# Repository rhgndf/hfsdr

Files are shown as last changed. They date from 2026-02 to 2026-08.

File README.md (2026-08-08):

# hfsdr

HFSDR: host software, firmware, and hardware design for the HFSDR USB device.




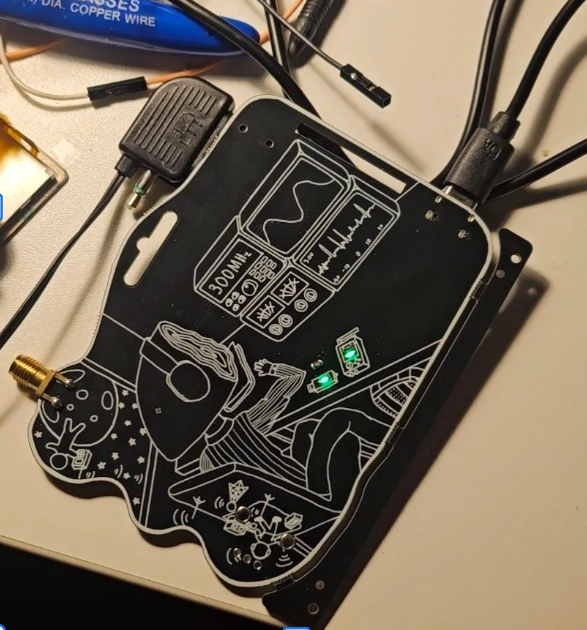
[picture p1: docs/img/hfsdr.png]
hfsdr


[Board PCB Files viewer](https://rhgndf.github.io/hfsdr/hardware)

## Getting started

Portable Mode (not connected to a PC)

1. Press the Rotary Encoder to 
    1. Enable/ Disable FM Audio Out mode (on disabled, it plays a constant tone)
    2. Cycle through different LED modes
<!--2. Turn the radio to change the FM Radio Frequency-->

Connected to a PC

1. Go to [the web ui](https://rhgndf.github.io/hfsdr/)
2. Connect & Pair a device
3. Set the frequency & gain
4. Pair the device again
5. Waterfall of the wireless world should start. If it doesn't look like [this](https://hackin7.github.io/lain-sdr-chall/assets/sample-C2LA0HHR.png), unplug the device and try again

- **User manual (slides):** [HFSDR User Manual](https://docs.google.com/presentation/d/1T5zb-2KSN37Saw5E9nwcajVOSR3CzVYfAOpIypQLBcQ/edit?usp=sharing)
- **Lain Themed Web UI** [lain-sdr-ui](https://hackin7.github.io/lain-sdr-chall)
- **Host testing (Python probe, GNU Radio `.grc` examples, drivers, protocol):** [docs/host-guide.md](docs/host-guide.md)

## Troubleshooting

- **No firmware:** Enter the bootloader by holding down BOOT and pressing the RST button. Use `wchisp` to flash the elf file in the releases
- **USB / stream flaky:** Unplug the board or reset it a few times. The host stack sometimes needs a power cycle before enumeration, WinUSB binding, or streaming stabilizes.
- **Using with GNURadio/ Python Scripting:** See the driver and probe sections in [docs/host-guide.md](docs/host-guide.md).
- **Reset:** Do not hold the reset button for too long 

## Repository layout

| Path | Contents |
|---|---|
| `ch32v305/` | Firmware (CH32V305). Build, flash, toolchain: [ch32v305/README.md](ch32v305/README.md). |
| `client-sw/` | Host Python (`hfsdr_probe`, PyUSB helpers), GNU Radio blocks and examples (`gr-hfsdr-lib`, `.grc`). |
| `docs/` | [host-guide.md](docs/host-guide.md) — primary host-side documentation. |
| `hardware/` | KiCad project and related hardware files. |
| `scripts/` | Helper scripts (e.g. udev `99-hfsdr.rules`, Windows USB checks). |
| `ui/` | WebUSB Web UI (Svelte/Vite). Deployed build: `homepage` in [ui/package.json](ui/package.json). |

## Credits

1. rhgndf - hard carry schematic & everything inside actually
2. Hackin7 - Art, PCB rough layout & routing & some embedded
3. Hack & Roll Cursor Credits + Codex - allow us to do this while being overseas/ having full time jobs
4. https://github.com/ttrftech/CentSDR - Useful reference

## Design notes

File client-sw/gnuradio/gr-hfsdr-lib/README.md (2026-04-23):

# gr-hfsdr-lib

Python-first GNU Radio source scaffold for HFSDR over the USB vendor endpoint.

Full host setup (drivers, probe, opening example `.grc` files, protocol): [docs/host-guide.md](../../../docs/host-guide.md).

## What this scaffold provides

- `python/hfsdr_source.py`: GNU Radio `sync_block` source outputting `gr_complex`.
- `python/hfsdr_usb.py`: PyUSB transport and vendor control requests.
- `grc/hfsdr_hfsdr_source.block.yml`: GRC block description for quick graph wiring.

## Dependencies

- GNU Radio 3.10+
- Python packages:
  - `numpy`
  - `pyusb`

Install:

```bash
py -3 -m pip install -r client-sw/host/python/requirements.txt
```

## Quick use from Python flowgraph

```python
import os
import sys
sys.path.insert(0, os.path.abspath("client-sw/gnuradio/gr-hfsdr-lib/python"))
from hfsdr_source import hfsdr_source

src = hfsdr_source(sample_rate=192000, vid=0xCAFE, pid=0x4031, interface=4, endpoint_in=0x85)
```

## Runtime controls

- `set_lo_hz(hz)`
- `get_lo_hz()`
- `set_gain_raw(gain_raw)`
- `get_pll_locked()`
- `get_stats()`

You can also set `gain_raw` in the GRC block parameters and enable
`apply_gain_on_start` to program TLV320 gain when the flowgraph starts.

## Notes

- The source claims only the vendor interface, so CDC and UAC interfaces remain available.
- This is an initial scaffold intended for rapid bring-up. If needed, migrate to a full compiled OOT layout later.

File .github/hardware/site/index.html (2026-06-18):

KiCad CI review

# __PROJECT_NAME__

Run GitHub Actions

Commit unknown

ERC / DRC unknown

Outputs unknown

3D unknown

## KiCanvas

Interactive schematic and PCB view from the source files in this run.

## Visual Diff

Schematic and PCB differences for this pull request.

### Visual diff

Open full SVG

## 3D Model

The browser VRML viewer is enabled automatically when a board model is available.

### No browser-viewable 3D model in this run

The 3D model job did not publish model/board.wrl for this project.

## ERC and DRC Reports

Generated by KiBot during the validation job.

### ERC

Open full report

### DRC

Open full report

## Downloads

Fabrication and assembly files from this run.

Generic BOM CSV Generic fabrication ZIP JLCPCB Gerbers ZIP JLCPCB BOM CSV JLCPCB CPL CSV Interactive BOM

## PDFs

Schematic and PCB layer plots from KiBot.

Schematic Front copper Back copper Front silkscreen Back silkscreen Front mask Back mask Front fab Back fab Edge cuts

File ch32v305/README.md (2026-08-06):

# ch32v305

Firmware build for the CH32V305 SDR target.

## Requirements

- `cmake` 3.20 or newer
- `ninja`
- RISC-V GCC bare-metal toolchain in `PATH`
  - expected tools: `riscv-none-elf-gcc`, `riscv-none-elf-g++`, `riscv-none-elf-ar`, `riscv-none-elf-size`

## Build With Ninja

Configure the project with the Ninja generator:

```bash
cmake -S . -B build -G Ninja
```

Build it:

```bash
cmake --build build
```

The main output is:

- `build/ch32v305_sdr.elf`

The linker also emits:

- `build/ch32v305_sdr.map`

## Flash

From the build directory:

```bash
cd build
wchisp flash ch32v305_sdr.elf
```

## Notes

- Link-time output includes `--print-memory-usage`.
- A post-build `riscv-none-elf-size` report is also printed.
- FreeRTOS Kernel is a submodule pinned to V11.3.0. Initialize submodules before
  building a fresh checkout:

  ```bash
  git submodule update --init --recursive
  ```
- All FreeRTOS objects and tasks use static allocation. The task layout is:

  | Task | Priority | Stack |
  | --- | ---: | ---: |
  | I2S processing | 3 | 192 words / 768 bytes |
  | TinyUSB device | 2 | 256 words / 1024 bytes |
  | Hardware state | 2 | 256 words / 1024 bytes |
  | Recording | 2 | 432 words / 1728 bytes |
  | Application/UI | 1 | 432 words / 1728 bytes |
  | FreeRTOS idle | 0 | 144 words / 576 bytes |

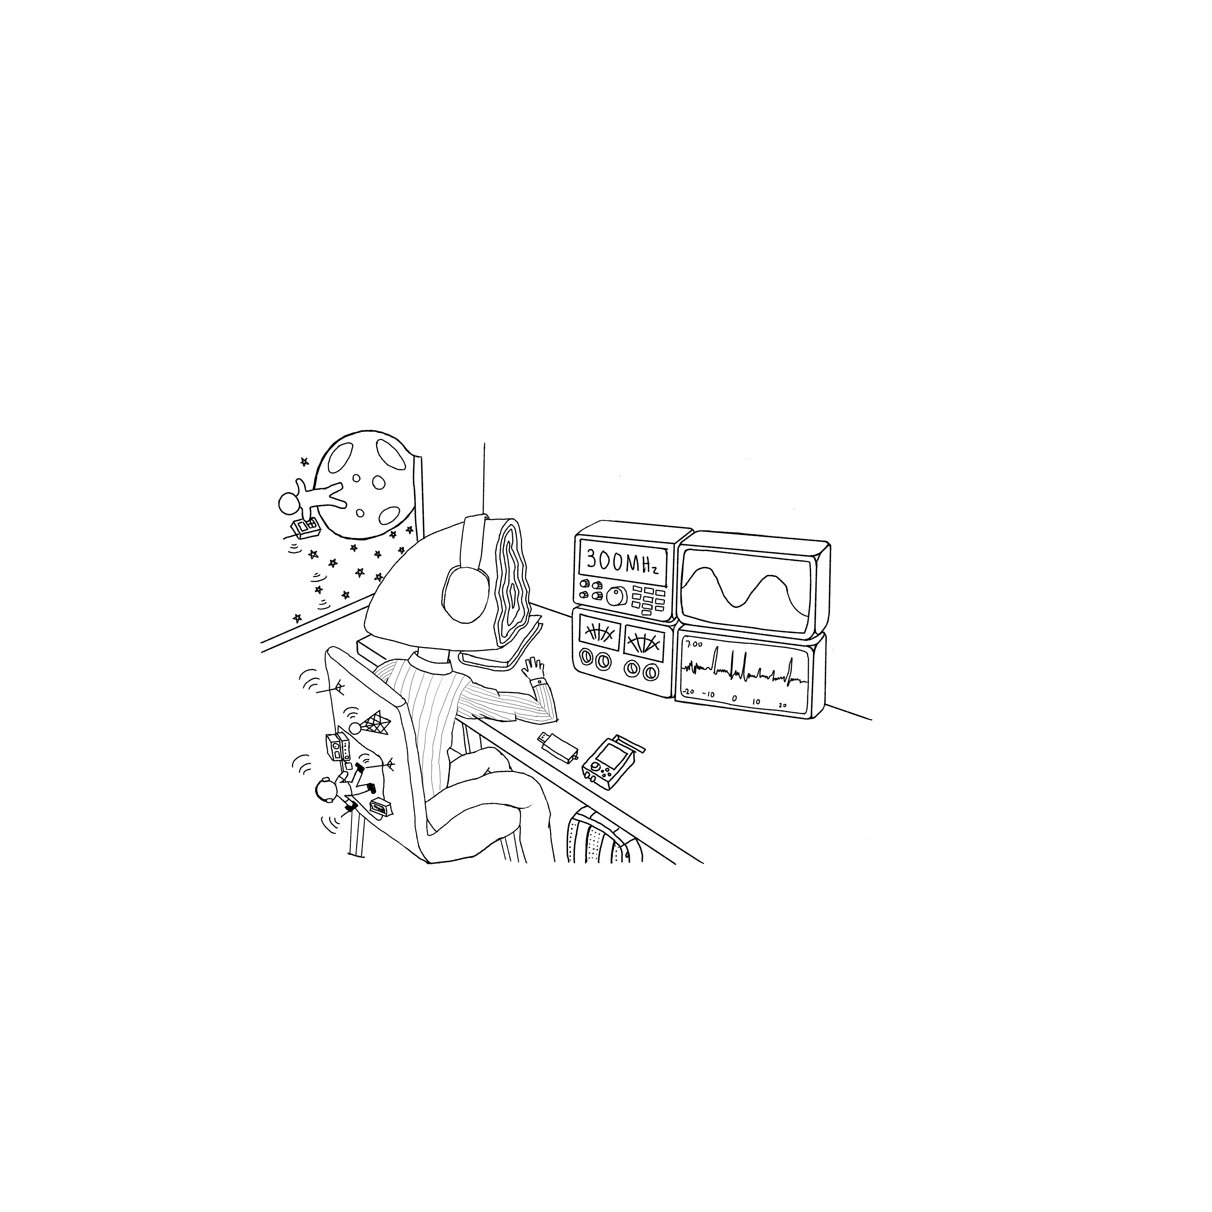
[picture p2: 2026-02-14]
art/art_export/design1- silkscreen.png

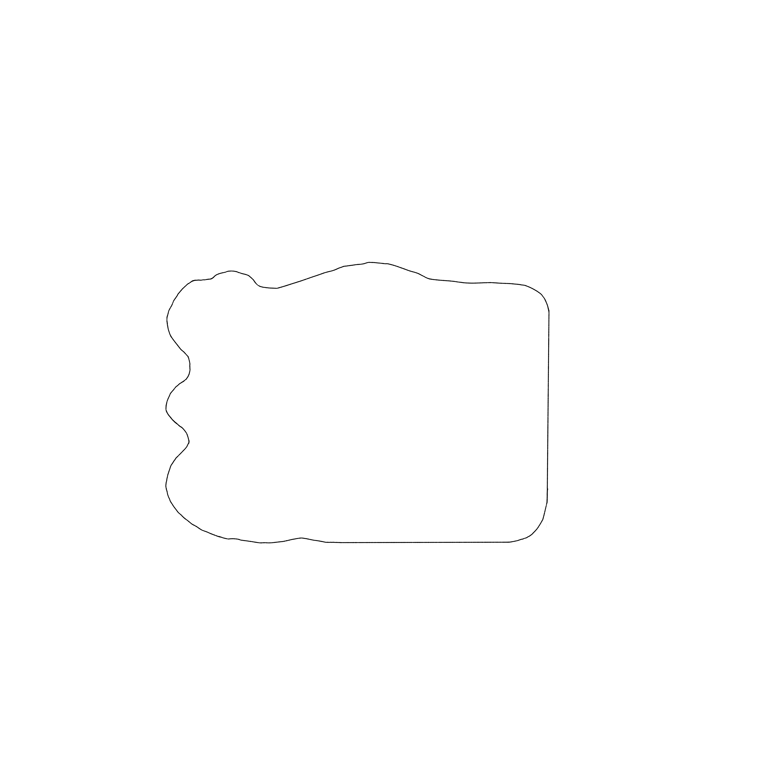
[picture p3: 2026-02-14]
art/art_export/design1-outline.png

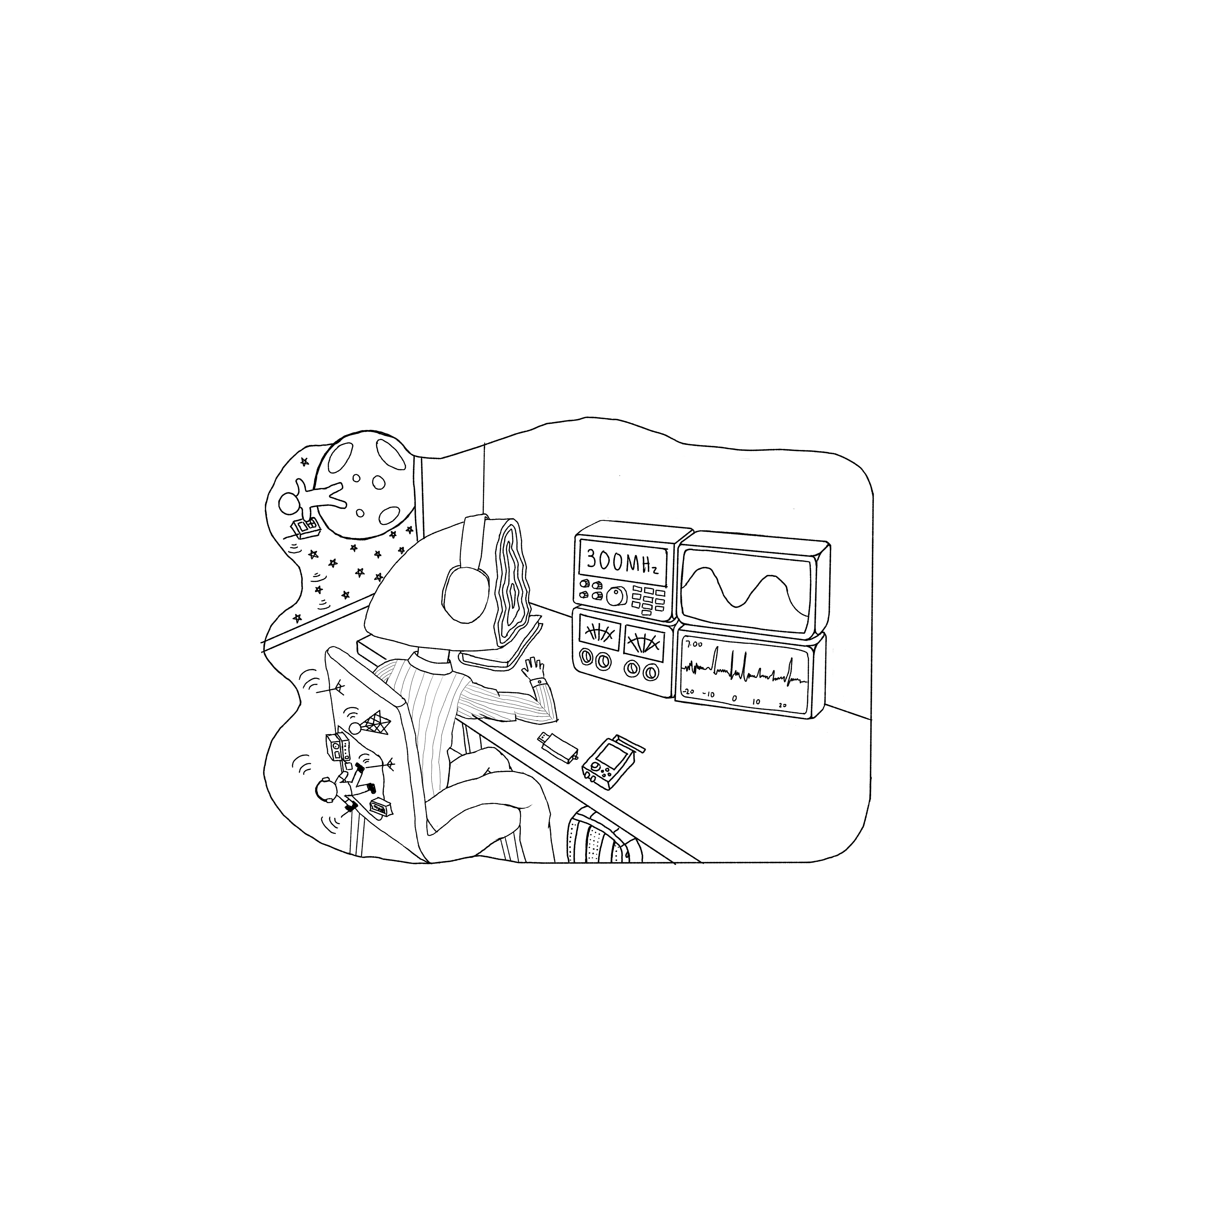
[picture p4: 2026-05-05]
art/art_export/design1-silkscreen_over_outline.png

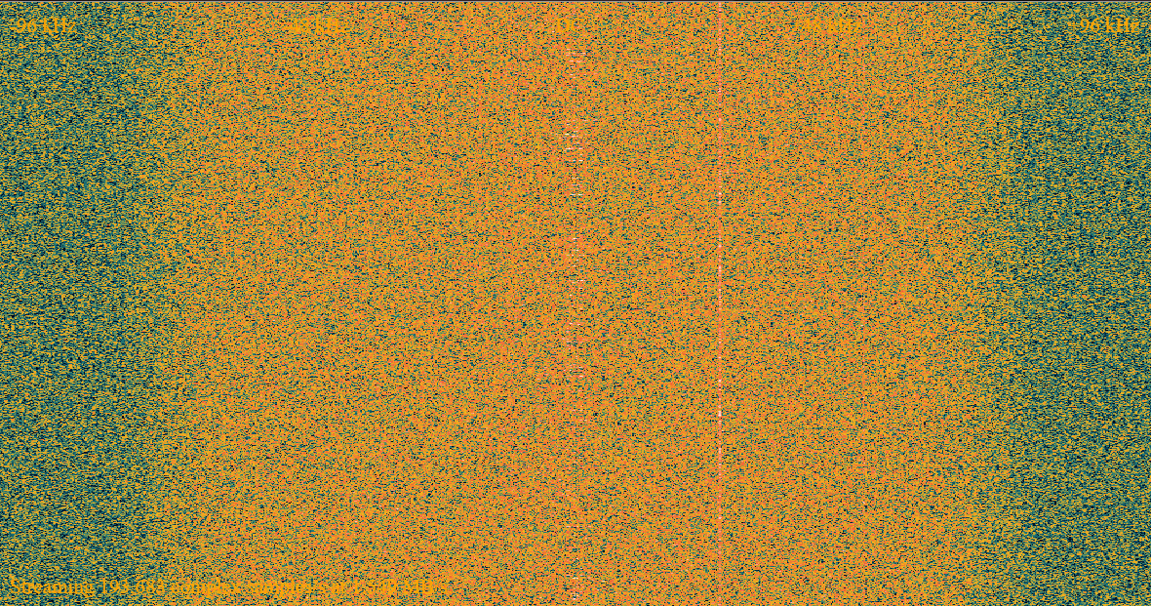
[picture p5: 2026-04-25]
ui/src/assets/sample.png

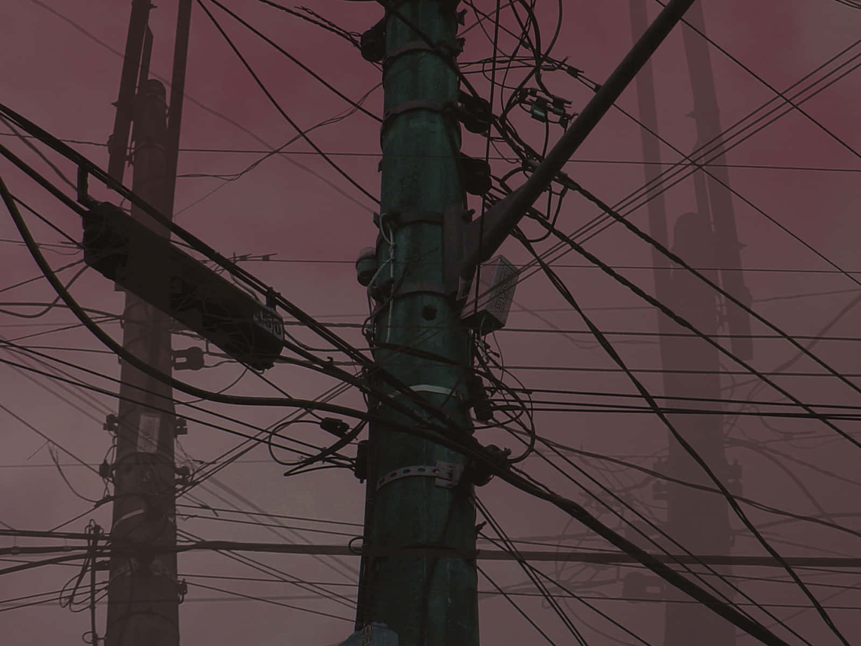
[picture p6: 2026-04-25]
ui/src/assets/lain_background.jpg

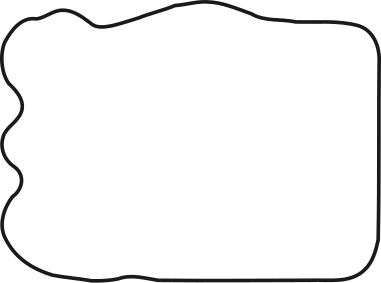
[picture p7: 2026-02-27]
art/pcb_files/silkscreen.png

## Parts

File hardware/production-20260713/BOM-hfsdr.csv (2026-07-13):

Comment | Designator | Footprint | LCSC | Quantity
100k | R7 | R_0805_2012Metric_Pad1.20x1.40mm_HandSolder | C149504 | 1
100nF | C11,C12,C17,C18,C19,C2,C20,C22,C23,C34,C35,C37,C39,C4,C41,C47,C48,C49,C5,C50,C51,C52,C54,C55,C6,C7,C8 | C_0805_2012Metric_Pad1.18x1.45mm_HandSolder | C49678 | 27
100uF | C30,C31 | CP_EIA-3528-15_AVX-H_HandSolder | C16133 | 2
10k | R12,R13,R14,R23,R24,R25,R26,R27,R28,R29,R3,R4,R5,R6 | R_0805_2012Metric_Pad1.20x1.40mm_HandSolder | C17414 | 14
10nF | C3,C43,C44,C45,C46 | C_0805_2012Metric_Pad1.18x1.45mm_HandSolder | C97905 | 5
10uF | C33,C36,C40 | C_0805_2012Metric_Pad1.18x1.45mm_HandSolder | C15850 | 3
1N5819WS | D1 | D_SOD-323 | C191023 | 1
1uF | C1,C10,C13,C14,C15,C16,C21,C24,C25,C26,C27,C28,C29,C32,C38,C42,C53,C56,C9 | C_0805_2012Metric_Pad1.18x1.45mm_HandSolder | C28323 | 19
20k | R10,R11 | R_0805_2012Metric_Pad1.20x1.40mm_HandSolder | C4328 | 2
220pF | C57,C58,C59,C60 | C_0805_2012Metric_Pad1.18x1.45mm_HandSolder | C1790 | 4
2T024000VX | X1 | OSC-SMD_4P-L2.5-W2.0-BL_X1G0054210307 | C47018486 | 1
2k | R15,R16,R8,R9 | R_0805_2012Metric_Pad1.20x1.40mm_HandSolder | C17604 | 4
470 | R17,R18 | R_0805_2012Metric | C17710 | 2
47k | R19,R20,R21,R22 | R_0805_2012Metric_Pad1.20x1.40mm_HandSolder | C17713 | 4
5.1k | R1,R2 | R_0805_2012Metric_Pad1.20x1.40mm_HandSolder | C27834 | 2
AO3401A | Q1 | SOT-23 | C15127 | 1
AudioPlug4 | J2 | Jack_3.5mm_KoreanHropartsElec_PJ-320D-4A_Horizontal | C95562 | 1
BAV99 | D5 | SOT-23 | C7420336 | 1
BGA2817 | U6 | SOT-363_SC-70-6 | C2654187 | 1
BOOT0 | SW2 | SW_Push_1P1T_XKB_TS-1187A | C318884 | 1
BWSMA-KE-P001 | RF1 | SMA-SMD_BWSMA-KE-P001 | C496550 | 1
CH32V30xRxTx | U3 | LQFP-64_10x10mm_P0.5mm | C5187529 | 1
FPC-05F-18PH20 | FPC1 | FPC-SMD_18P-P0.50_FPC-05F-18PH20 | C2856802 | 1
GZ2012D601TF | FB1,FB2,FB3,FB4,FB5 | L_0805_2012Metric_Pad1.05x1.20mm_HandSolder | C1017 | 5
JST PH S2B | J4 | JST_PH_S2B-PH-SM4-TB_1x02-1MP_P2.00mm_Horizontal | C7433648 | 1
LED | D2 | LED_0805_2012Metric | C2297 | 1
LED | D3,D4 | LED1206-RD_RED_XL-3216SURC-FB | C3646941 | 2
LM4809 | U8 | MSOP-8_L3.0-W3.0-P0.65-LS4.9-BL | C5125075 | 1
MD57E33QC3 | U4,U5 | SOT-23-5_L3.0-W1.7-P0.95-LS2.8-BR | C920562 | 2
MST-22D18G4-WT | SW3 | SW-SMD_MST-22D18G4-WT | C7507448 | 1
RST | SW1 | SW_Push_1P1T_XKB_TS-1187A | C318884 | 1
SN74CBTLV3253 | U1 | SOIC-16_3.9x9.9mm_P1.27mm | C543079 | 1
Si5351A-B-GT | Y1 | MSOP-10_3x3mm_P0.5mm | C1509083 | 1
TF-018B-H15 | TF1 | TF-SMD_TF-018B-H15 | C2962372 | 1
TP4054 | U7 | TSOT-23-5 | C32574 | 1
USB_C_Receptacle_USB2.0_16P | J1 | USB_C_Receptacle_GCT_USB4105-xx-A_16P_TopMnt_Horizontal | C2765186 | 1
XLV320ADC6120IRTER | U2 | RTE0020A-MFG | C2874822 | 1
RotaryEncoder_Switch | SW4 | RotaryEncoder_Alps_EC11E-Switch_Vertical_H20mm_MountingHoles |  | 1
TestPoint | TP20 | TestPoint_Pad_1.0x1.0mm |  | 1
TestPoint | TP16 | TestPoint_Pad_1.0x1.0mm |  | 1
TestPoint | TP12 | TestPoint_Pad_1.0x1.0mm |  | 1
TestPoint | TP10 | TestPoint_Pad_1.0x1.0mm |  | 1
TestPoint | TP7 | TestPoint_Pad_1.0x1.0mm |  | 1
TestPoint | TP17 | TestPoint_Pad_1.0x1.0mm |  | 1
TestPoint | TP4 | TestPoint_Pad_1.0x1.0mm |  | 1
TestPoint | TP6 | TestPoint_Pad_1.0x1.0mm |  | 1
TestPoint | TP3 | TestPoint_Pad_1.0x1.0mm |  | 1
TestPoint | TP22 | TestPoint_Pad_1.0x1.0mm |  | 1
TestPoint | TP9 | TestPoint_Pad_1.0x1.0mm |  | 1
TestPoint | TP1 | TestPoint_Pad_1.0x1.0mm |  | 1
TestPoint | TP18 | TestPoint_Pad_1.0x1.0mm |  | 1
TestPoint | TP13 | TestPoint_Pad_1.0x1.0mm |  | 1
TestPoint | TP11 | TestPoint_Pad_1.0x1.0mm |  | 1
TestPoint | TP21 | TestPoint_Pad_1.0x1.0mm |  | 1
TestPoint | TP15 | TestPoint_Pad_1.0x1.0mm |  | 1
TestPoint | TP14 | TestPoint_Pad_1.0x1.0mm |  | 1
TestPoint | TP5 | TestPoint_Pad_1.0x1.0mm |  | 1
TestPoint | TP2 | TestPoint_Pad_1.0x1.0mm |  | 1
TestPoint | TP19 | TestPoint_Pad_1.0x1.0mm |  | 1

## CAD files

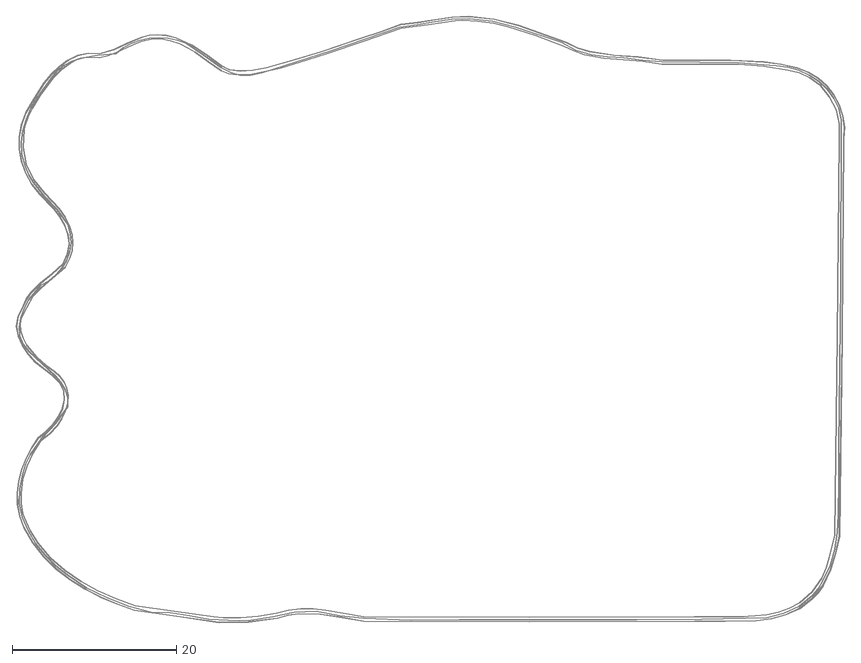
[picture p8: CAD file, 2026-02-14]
art/design1-outline.dxf
100.8 x 73.8

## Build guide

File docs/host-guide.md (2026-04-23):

# HFSDR host guide

This guide covers verifying the USB/IQ path with Python, running example GNU Radio Companion (`.grc`) flowgraphs, and reference material for drivers and the vendor protocol.

---

## Test the USB connection with Python

Use the probe script to confirm the OS stack, WinUSB/udev, and vendor bulk stream before GNU Radio.

### Dependencies

- Python 3
- Packages from the repo: `client-sw/host/python/requirements.txt` (includes `pyusb` and a working **libusb** backend; on Windows use a libusb-compatible driver on the vendor interface—see driver section below).

Install from the repository root:

```bash
py -3 -m pip install -r client-sw/host/python/requirements.txt
```

(Linux/macOS: `python3 -m pip install ...` as appropriate.)

### Run the probe

From the **repository root**:

```bash
python3 client-sw/host/python/hfsdr_probe.py --duration-s 5 --report-s 1
```

On Windows you can use `py -3` instead of `python3`.

### What “good” looks like

- Clock and PLL control requests return valid responses.
- Stream rate is stable and non-zero.
- First decoded IQ samples print.

### Extra probe modes (especially on Windows)

```powershell
py -3 client-sw/host/python/hfsdr_probe.py --doctor
py -3 client-sw/host/python/hfsdr_probe.py --list-devices
py -3 client-sw/host/python/hfsdr_probe.py --auto-interface --duration-s 3
```

If the doctor finds the device but cannot claim the interface, the vendor interface is usually not bound to WinUSB yet.

---

## GNU Radio: example `.grc` flowgraphs

Use **GNU Radio Companion** (3.10+) with the `gr-hfsdr-lib` blocks so the flowgraph can open the HFSDR source.

### 1. Dependencies and block path

- Install GNU Radio 3.10+.
- Install Python deps: `py -3 -m pip install -r client-sw/host/python/requirements.txt` (see [gr-hfsdr-lib README](../client-sw/gnuradio/gr-hfsdr-lib/README.md)).

<!--GNU Radio must find `gr-hfsdr-lib` Python modules and the block YAML. Typical options:

- Add the library `python` folder to `PYTHONPATH` before starting GRC, **or**
- Install/copy the OOT into a layout GNU Radio discovers (project uses a scaffold layout; see `gr-hfsdr-lib` README).

The block definition lives at `client-sw/gnuradio/gr-hfsdr-lib/grc/hfsdr_hfsdr_source.block.yml`.-->

For Windows, it is suggested to use Radioconda (Tested on Radioconda)

### 2. Open an example flowgraph

In GNU Radio Companion: **File → Open** and choose one of:

| Example | Path |
|---|---|
| Spectrum / waterfall style | `client-sw/gnuradio/examples/basic_spectrum_iq/basic_spectrum_iq.grc` |
| IQ record to file | `client-sw/gnuradio/examples/fm_iq_record_to_file.grc` |

Use **Generate** then **Execute**. You should see live plots updating while the device streams.

**If you see `No module named 'hfsdr_usb'`:** the Embedded Python Block adds `client-sw/host/python` to `sys.path` after it finds the repo root. Either start GNU Radio Companion with **working directory = the hfsdr repository root** (so discovery finds `client-sw/host/python/hfsdr_usb.py`), or set the block’s **`module_root` parameter** to the absolute path of that repo root (no extra quotes). The packaged **HFSDR WebUSB Source** block (`gr-hfsdr-lib`) resolves `hfsdr_usb` via the library folder automatically.

You can paste from `client-sw/gnuradio/examples/embedded_python_block_code.py` if you need a fresh Embedded Python Block body.

### 3. Suggested parameters (`basic_spectrum_iq`)

Baseline values aligned with the web UI intent:

- `samp_rate = 192000`
- `fft_size = 2048`
- `wf_update_s = 0.06`
- `wf_db_min = -110`
- `wf_db_max = -55`
- `dc_block_len = 64`
- `i_gain = 1.0`, `q_gain = 1.0`, `gain_const = 1.0`

Display path: embedded source → complex-to-float → per-branch gain → float-to-complex → DC blocker → GUI sinks.

### 4. Optional: Python demo (no `.grc`)

```bash
python3 client-sw/gnuradio/examples/hfsdr_webusb_demo.py
```

Expect spectrum and time sinks to update continuously, no repeated USB timeout loops, and clean stop when the window closes.

---

Warning - the documentation below is not vetted

## HFSDR WebUSB vendor protocol

This section defines the host-visible protocol for the HFSDR USB vendor interface so tools and GNU Radio blocks can interoperate across Windows/Linux.

### USB identity and interface map

- Vendor ID: `0xCAFE`
- Product ID: dynamic from TinyUSB PID bitmap (`0x4031` with current class set)
- Vendor interface number: `4` (`ITF_NUM_VENDOR`)
- Vendor bulk endpoints:
  - IN: `0x85` (device → host stream)
  - OUT: `0x05` (host → device, currently echo/debug path)
- Transport: USB Bulk transfers (not isochronous)

### Stream payload contract

The stream emitted on endpoint `0x85` is a byte sequence of little-endian 16-bit words copied directly from the I2S RX DMA half-buffer.

- Source buffer type in firmware: `volatile uint16_t[]`
- Words per DMA half-buffer push: `256`
- Bytes per DMA half-buffer push: `512`
- Sample structure:
  - 24-bit audio from TLV320 is captured in 32-bit I2S slots.
  - Each 32-bit slot appears as two 16-bit words in transfer order.
  - A stereo frame is 4 words (2 slots), i.e. 8 bytes.

Host-side reconstruction:

1. Group stream bytes into little-endian `uint16_t` words.
2. Pair words into 32-bit slots:
   - `slot = (word_hi << 16) | word_lo`
3. Reinterpret `slot` as signed 32-bit (`int32`), then scale to float:
   - `float = slot / 2147483648.0`
4. Pair adjacent slots into IQ:
   - `I = slot[0]`, `Q = slot[1]`, repeated.

Current firmware sends raw sample stream without sequence counter or frame marker. Drop detection should use:

- host USB timeout/read-gap monitoring,
- firmware drop counters (`usb_hw_vendor_dropped_words()` telemetry),
- optional future stream header framing if needed.

### Vendor control request contract

Requests use bmRequestType `vendor`. Recipient can be `device` (`wIndex=0`) or `interface` (`wIndex=ITF_NUM_VENDOR`); host tools should use interface recipient.

#### Request `1`: `VENDOR_REQUEST_WEBUSB`

- Direction: IN
- Purpose: fetch WebUSB landing page descriptor URL.

#### Request `2`: `VENDOR_REQUEST_MICROSOFT`

- Direction: IN
- Purpose: fetch Microsoft OS 2.0 descriptor set (`wIndex=7`) for WinUSB binding.

#### Request `3`: `VENDOR_REQUEST_SET_CLK_FREQ`

- Direction: OUT
- `wValue = 0`
- `wLength = 8`
- Payload: little-endian `uint64` frequency in Hz.
- Result: status stage success if Si5351 LO programming succeeds.

#### Request `4`: `VENDOR_REQUEST_GET_CLK_FREQ`

- Direction: IN
- `wValue = 0`
- Response length: 9 bytes:
  - byte `[0]`: `ErrorStatus` from firmware (`READY`/`NoREADY` enum value)
  - bytes `[1..8]`: little-endian `uint64` frequency in Hz.

#### Request `5`: `VENDOR_REQUEST_SET_TLV320_GAIN`

- Direction: OUT
- `wValue = 0`
- `wLength = 1`
- Payload: raw TLV320 gain register byte.
- Result: status stage success if TLV320 write succeeds.

#### Request `6`: `VENDOR_REQUEST_GET_PLL_LOCK`

- Direction: IN
- `wValue = 0`
- Response length: 2 bytes:
  - byte `[0]`: `ErrorStatus`
  - byte `[1]`: lock state (`0` unlocked, `1` locked)

### Host recommendations

- Read endpoint `0x85` with transfer sizes that are multiples of 512 bytes.
- Use multiple in-flight transfers or a dedicated reader thread.
- Keep USB read and decode separate via a ring buffer for GNU Radio integration.
- Claim only vendor interface `4` so CDC/UAC interfaces remain available.

---

## Extended validation checklist

Use after firmware flash and OS driver binding are correct.

### Runtime control checks

From a Python flowgraph shell or custom control script:

- `set_lo_hz(...)` changes tuner LO and observed spectrum shifts.
- `set_gain_raw(...)` changes measured signal amplitude.
- `get_pll_locked()` returns `1` during stable operation.

### Long run stability

Run for at least 10 minutes:

- No source freezes.
- No sustained growth in `read_errors` from `get_stats()`.
- `dropped_iq` remains low/acceptable for selected buffer size.

### Cross-platform parity

Repeat probe, GNU Radio smoke test, runtime checks, and long-run tests on:

- Windows (WinUSB on vendor interface).
- Linux (udev rule installed).

Record any differences in average stream throughput, USB timeout frequency, and startup reliability.

### UI-like spectrogram parity (GNU Radio vs browser)

Use `client-sw/gnuradio/examples/basic_spectrum_iq/basic_spectrum_iq.grc` and compare to the Web UI if applicable:

1. Set same LO frequency and ADC gain in both interfaces.
2. Verify DC-centered spectrum shape (carrier at expected offset from center).
3. Compare noise floor stability over 10–20 seconds.
4. Compare peak prominence for the same RF signal.
5. Verify retune response latency feels similar when changing LO.

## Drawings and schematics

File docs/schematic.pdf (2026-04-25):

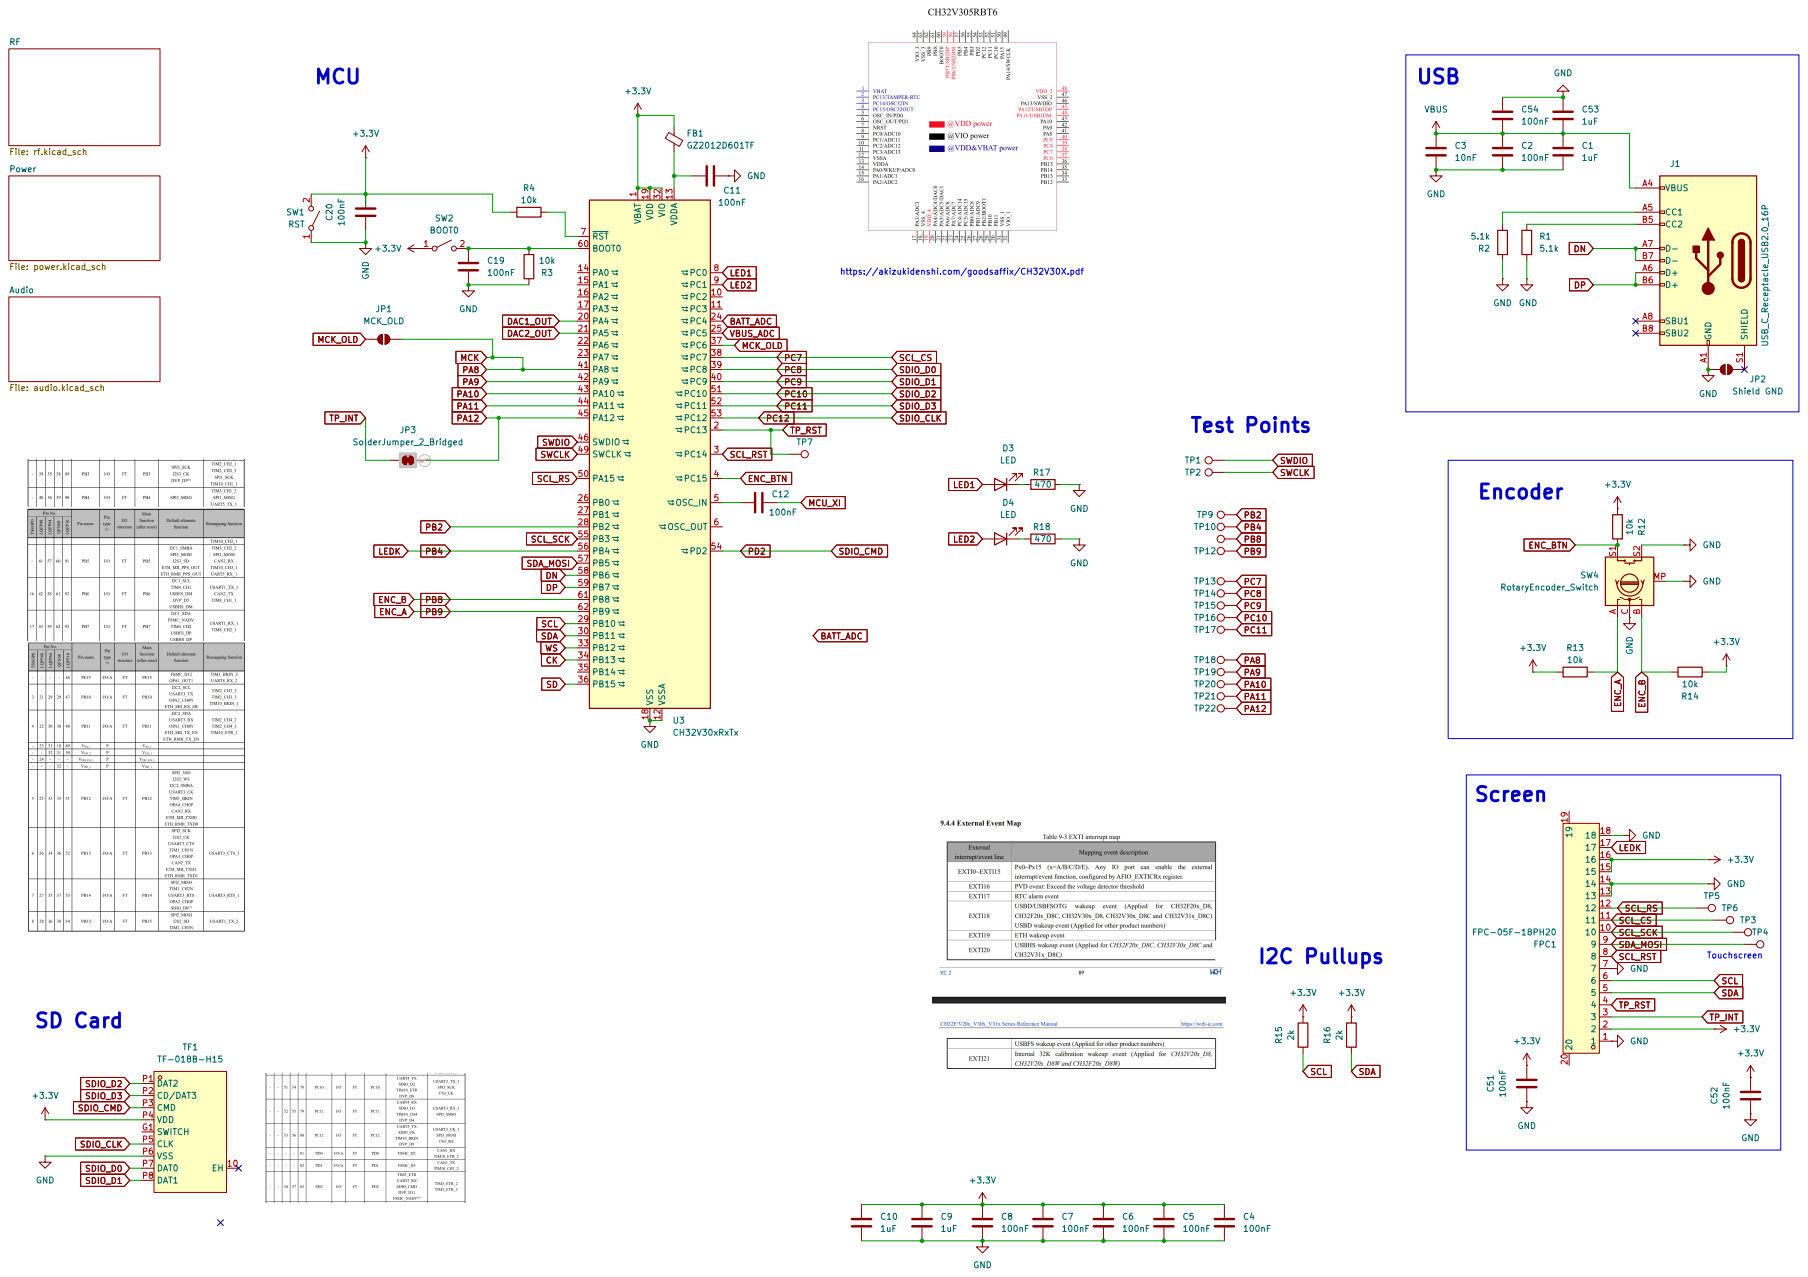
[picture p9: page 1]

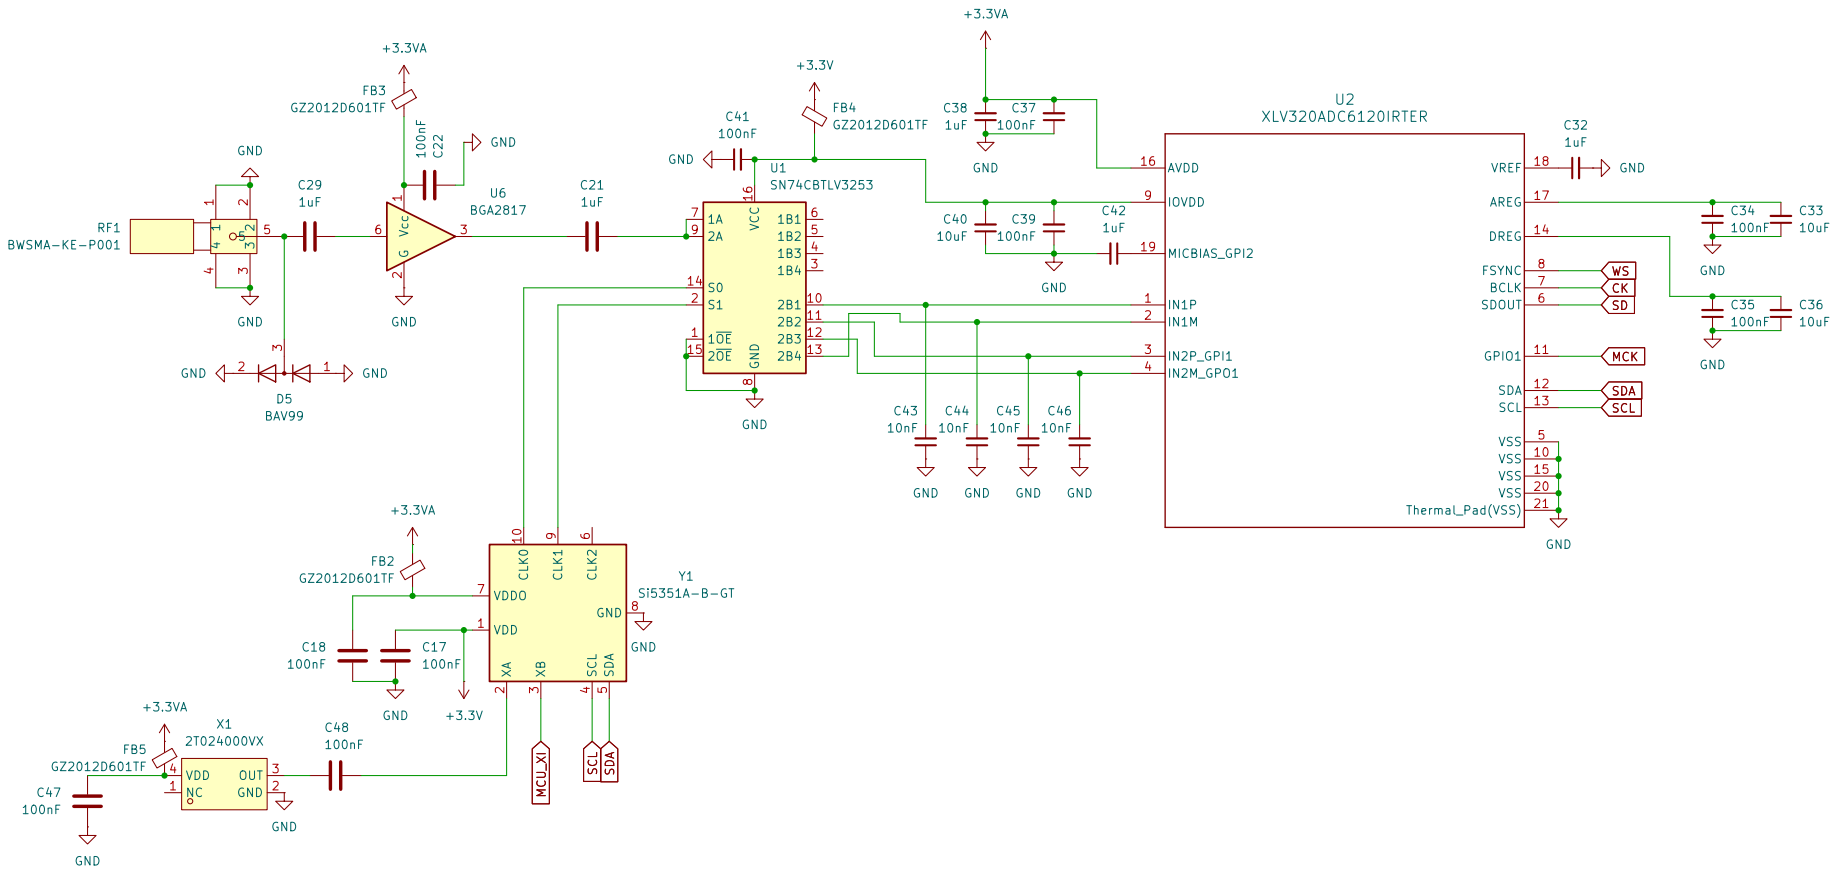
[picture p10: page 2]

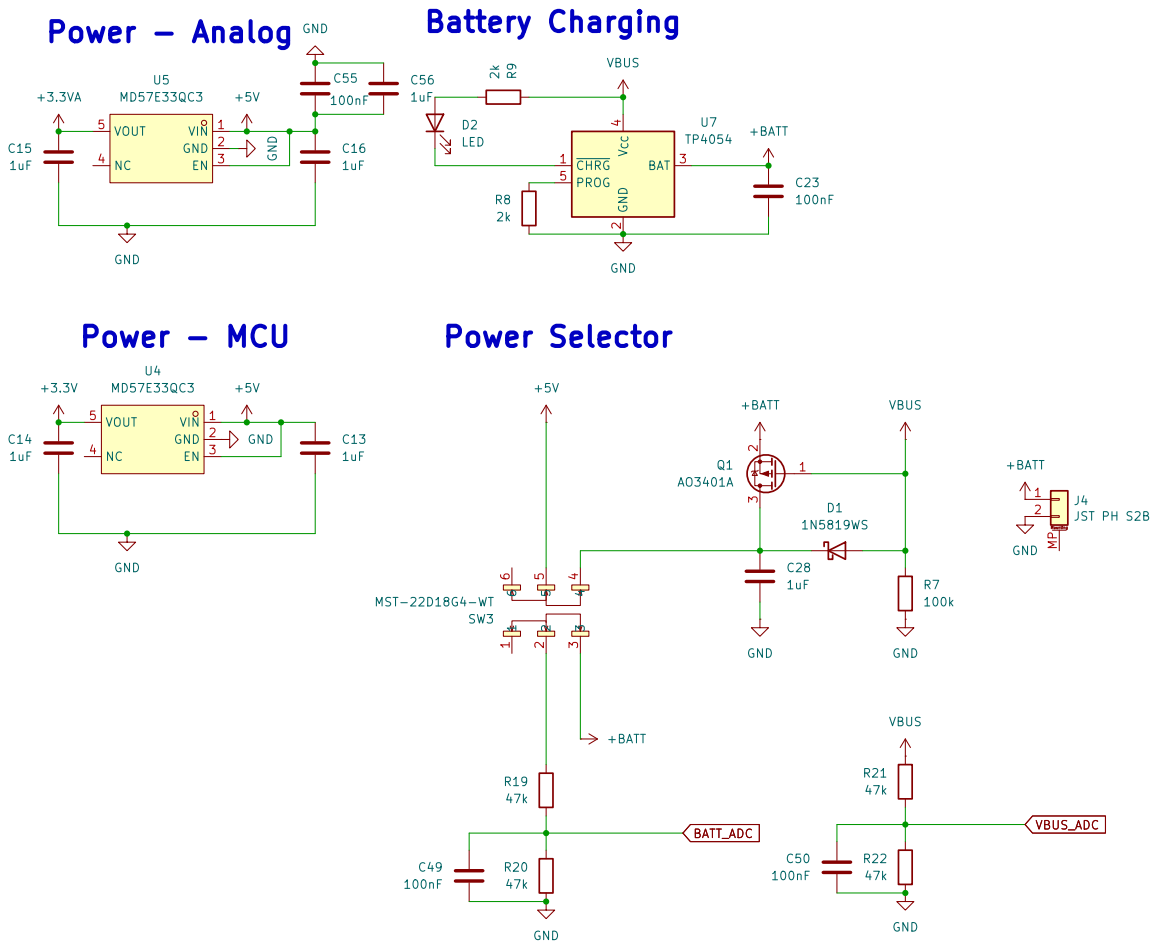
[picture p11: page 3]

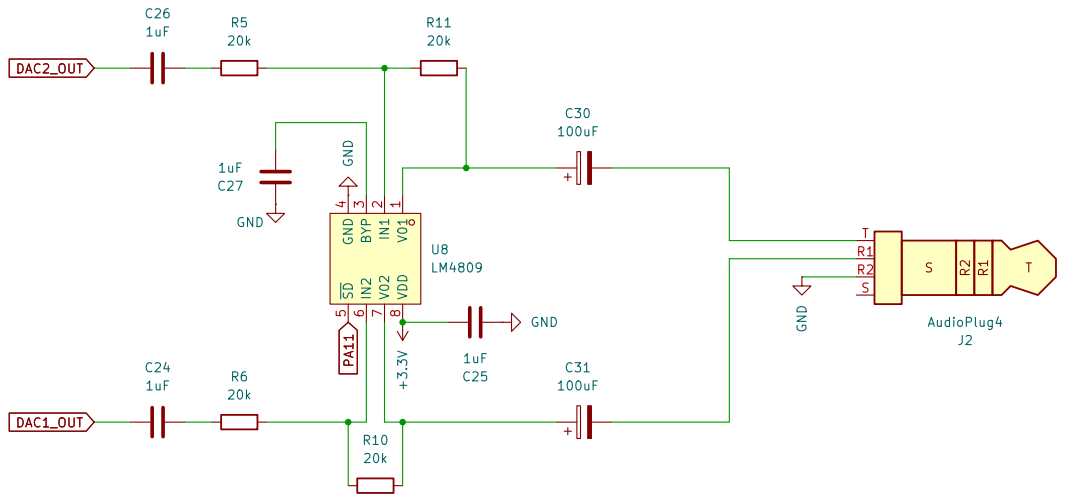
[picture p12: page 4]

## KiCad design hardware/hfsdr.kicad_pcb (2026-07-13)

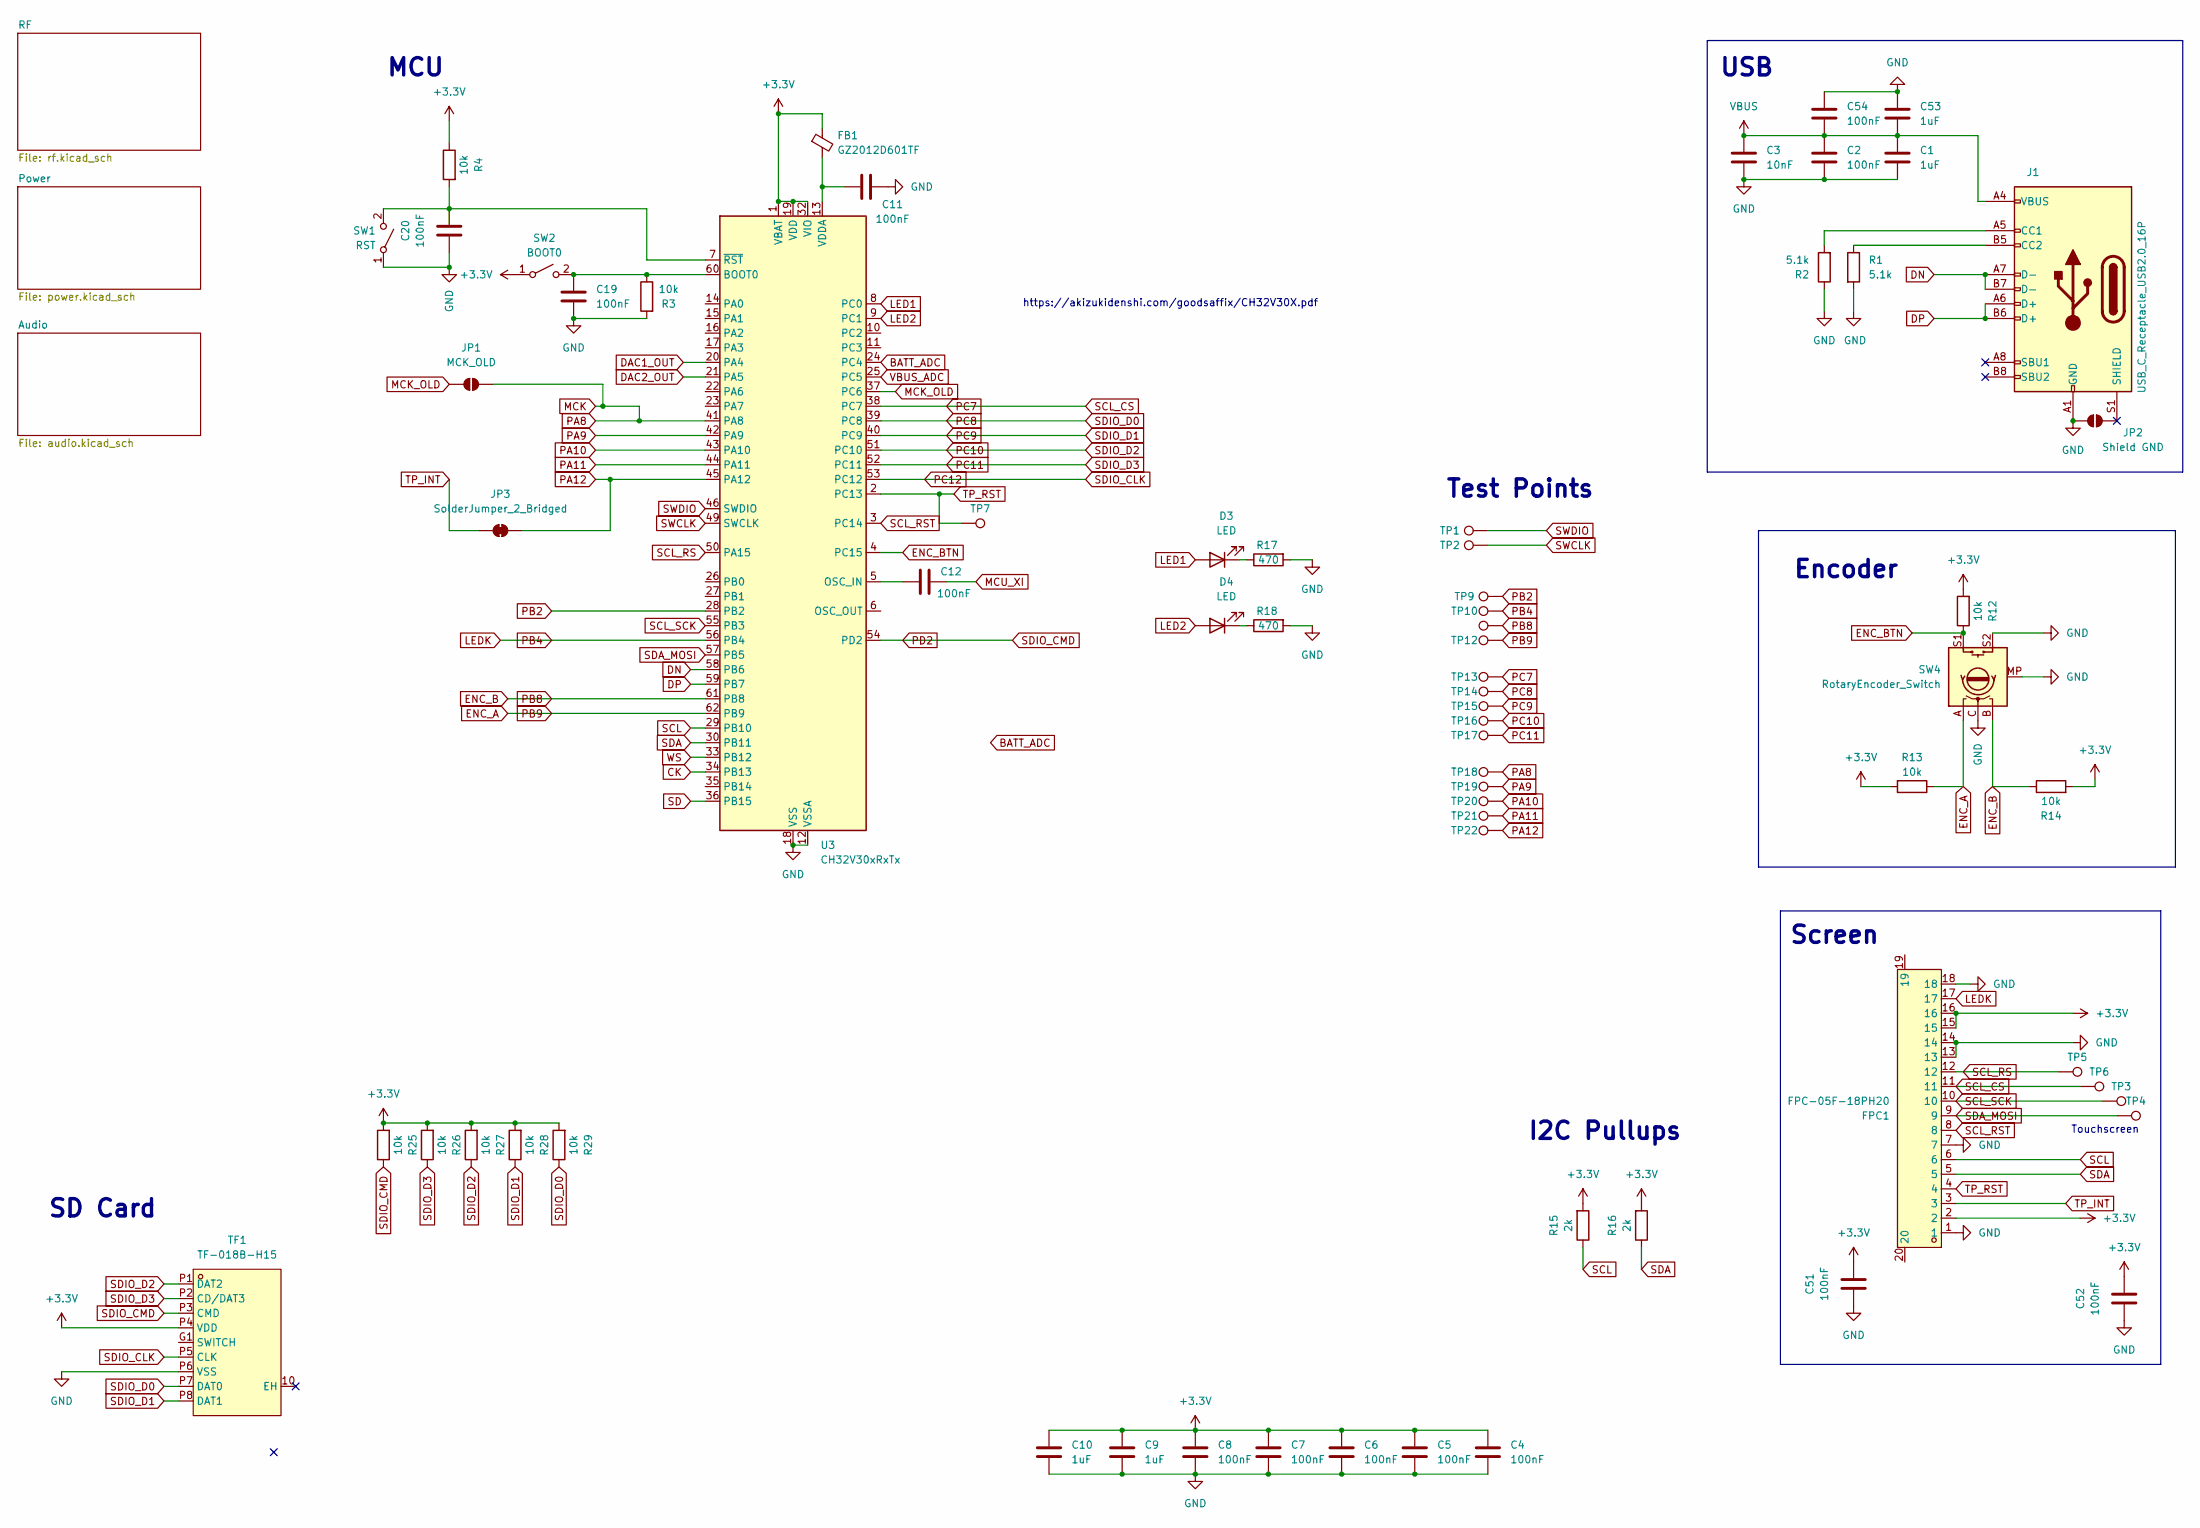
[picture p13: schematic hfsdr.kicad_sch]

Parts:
C1, C9, C10, C53: 1uF; C_0805_2012Metric_Pad1.18x1.45mm_HandSolder
C2, C4, C5, C6, C7, C8, C11, C12, C19, C20, C51, C52, C54: 100nF; C_0805_2012Metric_Pad1.18x1.45mm_HandSolder
C3: 10nF; C_0805_2012Metric_Pad1.18x1.45mm_HandSolder
D3, D4: LED; LED1206-RD_RED_XL-3216SURC-FB
FB1: GZ2012D601TF; L_0805_2012Metric_Pad1.05x1.20mm_HandSolder
FPC1: FPC-05F-18PH20; FPC-SMD_18P-P0.50_FPC-05F-18PH20; LCSC Part C2856802
J1: USB_C_Receptacle_USB2.0_16P; USB_C_Receptacle_GCT_USB4105-xx-A_16P_TopMnt_Horizontal
JP1: MCK_OLD; SolderJumper-2_P1.3mm_Open_RoundedPad1.0x1.5mm
JP2: Shield GND; SolderJumper-2_P1.3mm_Open_RoundedPad1.0x1.5mm
JP3: SolderJumper_2_Bridged; SolderJumper-2_P1.3mm_Bridged2Bar_RoundedPad1.0x1.5mm
R1, R2: 5.1k; R_0805_2012Metric_Pad1.20x1.40mm_HandSolder
R3, R4, R12, R13, R14, R25, R26, R27, R28, R29: 10k; R_0805_2012Metric_Pad1.20x1.40mm_HandSolder
R15, R16: 2k; R_0805_2012Metric_Pad1.20x1.40mm_HandSolder
R17, R18: 470; R_0805_2012Metric
SW1: RST; SW_Push_1P1T_XKB_TS-1187A
SW2: BOOT0; SW_Push_1P1T_XKB_TS-1187A
SW4: RotaryEncoder_Switch; RotaryEncoder_Alps_EC11E-Switch_Vertical_H20mm_MountingHoles
TF1: TF-018B-H15; TF-SMD_TF-018B-H15; LCSC Part C2962372
TP1, TP2, TP3, TP4, TP5, TP6, TP7, TP9, TP10, TP11, TP12, TP13, TP14, TP15, TP16, TP17, TP18, TP19, TP20, TP21, TP22: TestPoint; TestPoint_Pad_1.0x1.0mm
U3: CH32V30xRxTx; LQFP-64_10x10mm_P0.5mm

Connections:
+3.3V: C4.1, C5.1, C6.1, C7.1, C8.1, C9.1, C10.1, C51.2, C52.2, FB1.1, FPC1.2, FPC1.15, FPC1.16, R4.1, R12.2, R13.2, R14.2, R15.2, R16.2, R25.2, R26.2, R27.2, R28.2, R29.2, SW2.1 (A), TF1.P4 (VDD), U3.1 (VBAT), U3.19 (VDD), U3.32 (VIO), U3.48 (VDD), U3.64 (VIO); also elsewhere on the board
BATT_ADC: U3.24 (PC4); also elsewhere on the board
CK: U3.34 (PB13); also elsewhere on the board
DAC1_OUT: U3.20 (PA4); also elsewhere on the board
DAC2_OUT: U3.21 (PA5); also elsewhere on the board
DN: J1.A7 (D-), J1.B7 (D-), U3.58 (PB6)
DP: J1.A6 (D+), J1.B6 (D+), U3.59 (PB7)
ENC_A: R13.1, SW4.A, TP12.1 (1_1), U3.62 (PB9)
ENC_B: R14.1, SW4.B, TP11.1 (1_1), U3.61 (PB8)
ENC_BTN: R12.1, SW4.S1, U3.4 (PC15)
GND: C1.2, C2.2, C3.2, C4.2, C5.2, C6.2, C7.2, C8.2, C9.2, C10.2, C11.2, C19.2, C20.1, C51.1, C52.1, C53.1, C54.1, FPC1.1, FPC1.7, FPC1.13, FPC1.14, FPC1.18, J1.A1 (GND), J1.A12 (GND), J1.B1 (GND), J1.B12 (GND), JP2.1 (A_1), R1.2, R2.1, R3.2, R17.2, R18.2, SW1.1 (A), SW4.C, SW4.MP, SW4.S2, TF1.P6 (VSS), U3.12 (VSSA), U3.18 (VSS), U3.31 (VSS), U3.47 (VSS), U3.63 (VSS); also elsewhere on the board
LED1: D3.2 (A), U3.8 (PC0)
LED2: D4.2 (A), U3.9 (PC1)
LEDK: FPC1.17, TP10.1 (1_1), U3.56 (PB4)
MCK: JP1.2 (B), TP18.1 (1_1), U3.41 (PA8); also elsewhere on the board
MCK_OLD: JP1.1 (A), U3.37 (PC6)
MCU_XI: C12.2; also elsewhere on the board
unnamed: D3.1 (K), R17.1
unnamed: D4.1 (K), R18.1
unnamed: J1.A5 (CC1), R2.2
unnamed: J1.B5 (CC2), R1.1
unnamed: C20.2, R4.2, SW1.2 (B), U3.7 (~RST)
unnamed: C19.1, R3.1, SW2.2 (B), U3.60 (BOOT0)
unnamed: C12.1, U3.5 (OSC_IN)
unnamed: C11.1, FB1.2, U3.13 (VDDA)
PA9: TP19.1 (1_1), U3.42 (PA9)
PA10: TP20.1 (1_1), U3.43 (PA10)
PA11: TP21.1 (1_1), U3.44 (PA11); also elsewhere on the board
PA12: JP3.2 (B), TP22.1 (1_1), U3.45 (PA12)
PB2: TP9.1 (1_1), U3.28 (PB2)
PC7: FPC1.11, TP6.1 (1_1), TP13.1 (1_1), U3.38 (PC7)
PC8: R29.1, TF1.P7 (DAT0), TP14.1 (1_1), U3.39 (PC8)
PC9: R28.1, TF1.P8 (DAT1), TP15.1 (1_1), U3.40 (PC9)
PC10: R27.1, TF1.P1 (DAT2), TP16.1 (1_1), U3.51 (PC10)
PC11: R26.1, TF1.P2 (CD/DAT3), TP17.1 (1_1), U3.52 (PC11)
PC12: TF1.P5 (CLK), U3.53 (PC12)
PD2: R25.1, TF1.P3 (CMD), U3.54 (PD2)
SCL: FPC1.6, R15.1, U3.29 (PB10); also elsewhere on the board
SCL_RS: FPC1.12, TP5.1 (1_1), U3.50 (PA15)
SCL_RST: FPC1.8, U3.3 (PC14)
SCL_SCK: FPC1.10, TP3.1 (1_1), U3.55 (PB3)
SD: U3.36 (PB15); also elsewhere on the board
SDA: FPC1.5, R16.1, U3.30 (PB11); also elsewhere on the board
SDA_MOSI: FPC1.9, TP4.1 (1_1), U3.57 (PB5)
SWCLK: TP2.1 (1_1), U3.49 (SWCLK)
SWDIO: TP1.1 (1_1), U3.46 (SWDIO)
TP_INT: FPC1.3, JP3.1 (A)
TP_RST: FPC1.4, TP7.1 (1_1), U3.2 (PC13)
VBUS: C1.1, C2.1, C3.1, C53.2, C54.2, J1.A4 (VBUS), J1.A9 (VBUS), J1.B4 (VBUS), J1.B9 (VBUS); also elsewhere on the board
VBUS_ADC: U3.25 (PC5); also elsewhere on the board
WS: U3.33 (PB12); also elsewhere on the board

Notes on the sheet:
USB
SD Card
https://akizukidenshi.com/goodsaffix/CH32V30X.pdf
Encoder
Touchscreen
Screen
MCU
Test Points
I2C Pullups

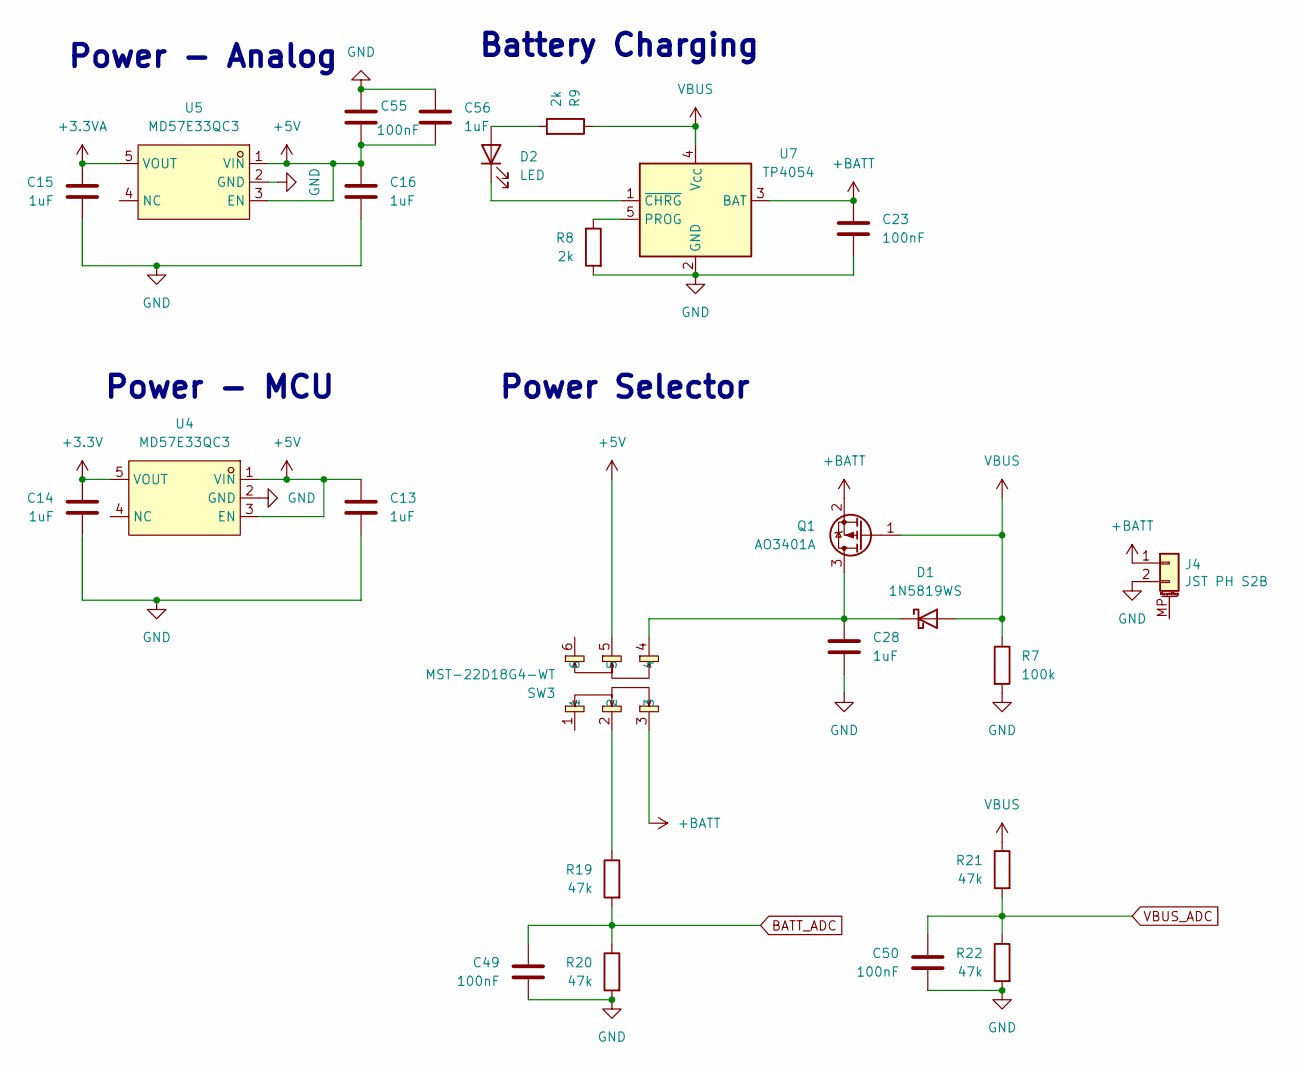
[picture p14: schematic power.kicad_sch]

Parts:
C13, C14, C15, C16, C28, C56: 1uF; C_0805_2012Metric_Pad1.18x1.45mm_HandSolder
C23, C49, C50, C55: 100nF; C_0805_2012Metric_Pad1.18x1.45mm_HandSolder
D1: 1N5819WS; D_SOD-323
D2: LED; LED_0805_2012Metric
J4: JST PH S2B; JST_PH_S2B-PH-SM4-TB_1x02-1MP_P2.00mm_Horizontal; LCSC C505023
Q1: AO3401A; SOT-23
R7: 100k; R_0805_2012Metric_Pad1.20x1.40mm_HandSolder
R8, R9: 2k; R_0805_2012Metric_Pad1.20x1.40mm_HandSolder
R19, R20, R21, R22: 47k; R_0805_2012Metric_Pad1.20x1.40mm_HandSolder
SW3: MST-22D18G4-WT; SW-SMD_MST-22D18G4-WT; LCSC Part C7507448
U4, U5: MD57E33QC3; SOT-23-5_L3.0-W1.7-P0.95-LS2.8-BR; LCSC Part C920562
U7: TP4054; TSOT-23-5

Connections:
+3.3V: C14.1, U4.5 (VOUT); also elsewhere on the board
+3.3VA: C15.1, U5.5 (VOUT); also elsewhere on the board
+5V: C13.1, C16.1, C55.2, C56.2, SW3.5, U4.1 (VIN), U4.3 (EN), U5.1 (VIN), U5.3 (EN)
+BATT: C23.1, J4.1, Q1.2 (S), SW3.3, U7.3 (BAT)
BATT_ADC: C49.1, R19.2, R20.1; also elsewhere on the board
GND: C13.2, C14.2, C15.2, C16.2, C23.2, C28.2, C49.2, C50.2, C55.1, C56.1, J4.2, R7.2, R8.2, R20.2, R22.2, U4.2 (GND), U5.2 (GND), U7.2 (GND); also elsewhere on the board
unnamed: C28.1, D1.1 (K), Q1.3 (D), SW3.4
unnamed: D2.2 (A), R9.2
unnamed: D2.1 (K), U7.1 (~CHRG)
unnamed: R19.1, SW3.2
unnamed: R8.1, U7.5 (PROG)
VBUS: D1.2 (A), Q1.1 (G), R7.1, R9.1, R21.1, U7.4 (V_{CC}); also elsewhere on the board
VBUS_ADC: C50.1, R21.2, R22.1; also elsewhere on the board

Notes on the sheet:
Power - Analog
Battery Charging
Power - MCU
Power Selector

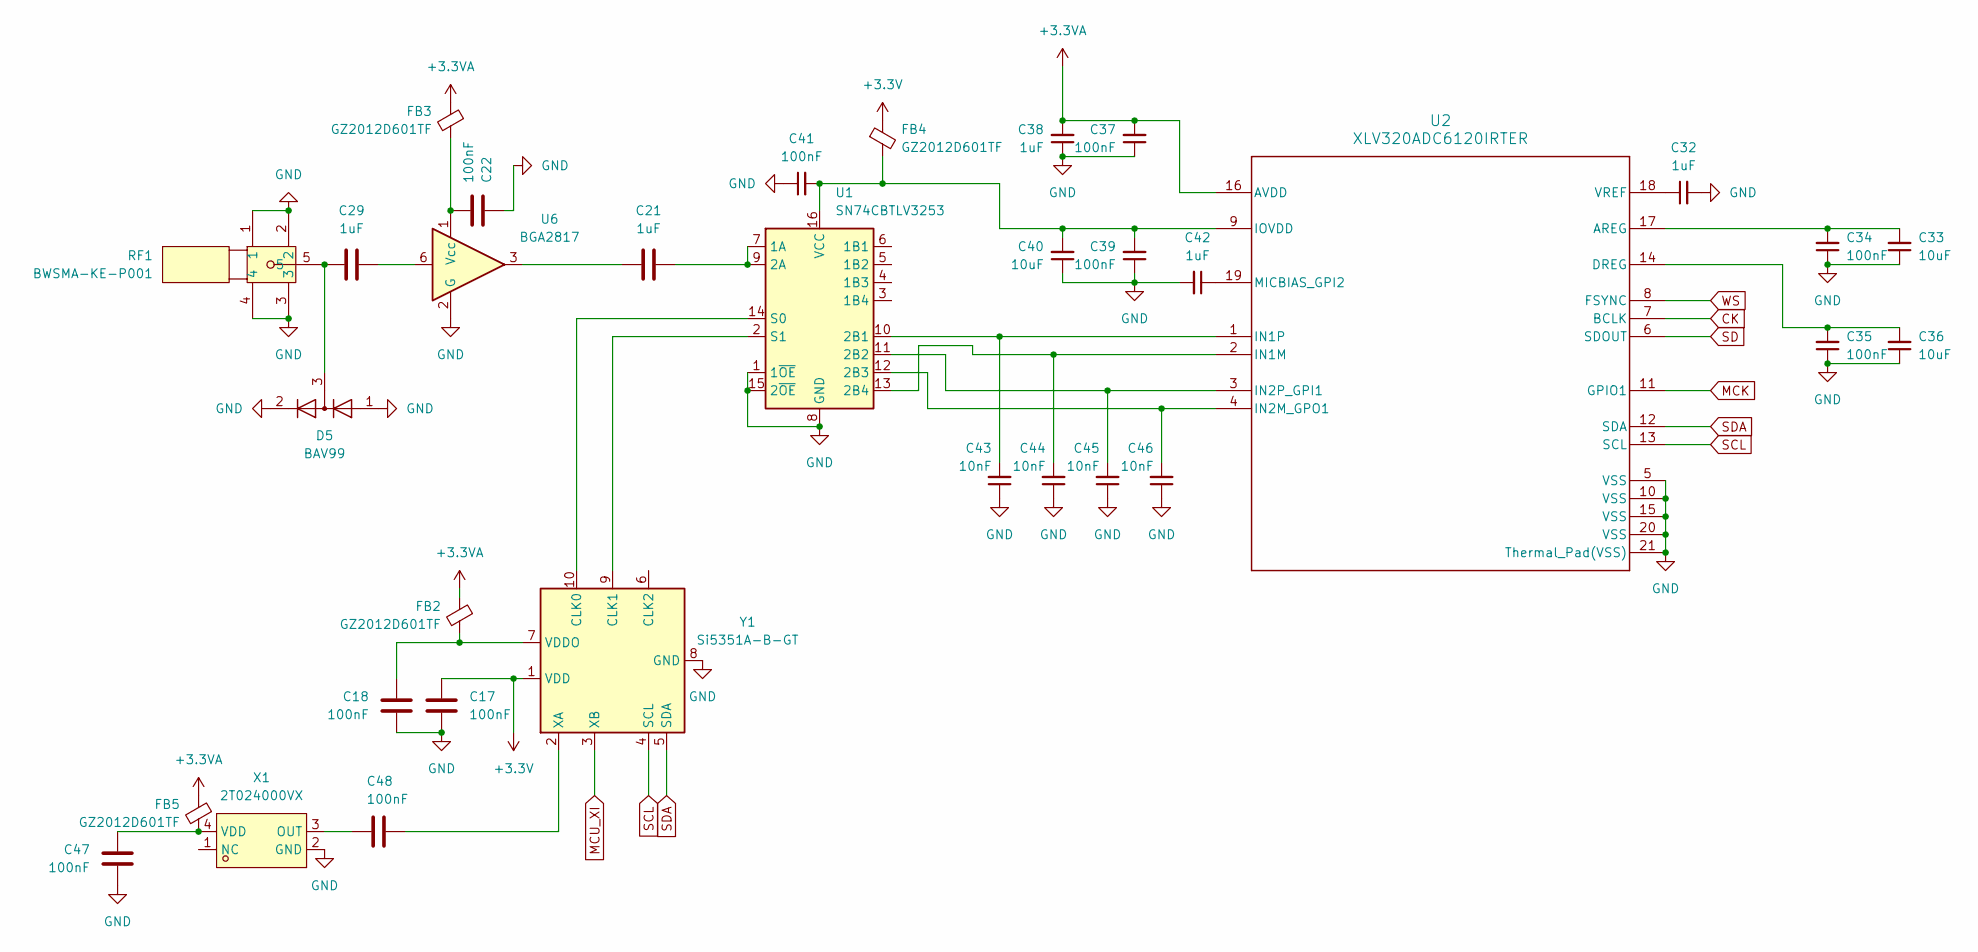
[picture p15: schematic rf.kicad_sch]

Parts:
C17, C18, C22, C34, C35, C37, C39, C41, C47, C48: 100nF; C_0805_2012Metric_Pad1.18x1.45mm_HandSolder
C21, C29, C32, C38, C42: 1uF; C_0805_2012Metric_Pad1.18x1.45mm_HandSolder
C33, C36, C40: 10uF; C_0805_2012Metric_Pad1.18x1.45mm_HandSolder
C43, C44, C45, C46: 10nF; C_0805_2012Metric_Pad1.18x1.45mm_HandSolder
D5: BAV99; SOT-23
FB2, FB3, FB4, FB5: GZ2012D601TF; L_0805_2012Metric_Pad1.05x1.20mm_HandSolder
RF1: BWSMA-KE-P001; SMA-SMD_BWSMA-KE-P001; LCSC Part C496550
U1: SN74CBTLV3253; SOIC-16_3.9x9.9mm_P1.27mm
U2: XLV320ADC6120IRTER; RTE0020A-MFG
U6: BGA2817; SOT-363_SC-70-6
X1: 2T024000VX; OSC-SMD_4P-L2.5-W2.0-BL_X1G0054210307; LCSC Part C47018486
Y1: Si5351A-B-GT; MSOP-10_3x3mm_P0.5mm

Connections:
+3.3V: C17.2, FB4.1, Y1.1 (VDD); also elsewhere on the board
+3.3VA: C37.2, C38.2, FB2.1, FB3.1, FB5.1, U2.16 (AVDD); also elsewhere on the board
CK: U2.7 (BCLK); also elsewhere on the board
GND: C17.1, C18.2, C22.1, C32.2, C33.1, C34.1, C35.1, C36.1, C37.1, C38.1, C39.1, C40.1, C41.1, C42.2, C43.1, C44.1, C45.1, C46.1, C47.2, D5.1 (K), D5.2 (A), RF1.1, RF1.2, RF1.3, RF1.4, U1.1 (1~OE), U1.8 (GND), U1.15 (2~OE), U2.5 (VSS), U2.10 (VSS), U2.15 (VSS), U2.20 (VSS), U2.21 (Thermal_Pad(VSS)), U6.2 (G), U6.4 (G), U6.5 (G), X1.2 (GND), Y1.8 (GND); also elsewhere on the board
MCK: U2.11 (GPIO1); also elsewhere on the board
MCU_XI: Y1.3 (XB); also elsewhere on the board
unnamed: C21.2, U6.3
unnamed: C29.1, U6.6
unnamed: C29.2, D5.3 (K), RF1.5
unnamed: C21.1, U1.7 (1A), U1.9 (2A)
unnamed: C43.2, U1.10 (2B1), U2.1 (IN1P)
unnamed: C45.2, U1.11 (2B2), U2.3 (IN2P_GPI1)
unnamed: C46.2, U1.12 (2B3), U2.4 (IN2M_GPO1)
unnamed: C44.2, U1.13 (2B4), U2.2 (IN1M)
unnamed: U1.14 (S0), Y1.10 (CLK0)
unnamed: U1.2 (S1), Y1.9 (CLK1)
unnamed: C39.2, C40.2, C41.2, FB4.2, U1.16 (VCC), U2.9 (IOVDD)
unnamed: C33.2, C34.2, U2.17 (AREG)
unnamed: C35.2, C36.2, U2.14 (DREG)
unnamed: C42.1, U2.19 (MICBIAS_GPI2)
unnamed: C32.1, U2.18 (VREF)
unnamed: C22.2, FB3.2, U6.1 (Vcc)
unnamed: C48.2, X1.3 (OUT)
unnamed: C47.1, FB5.2, X1.4 (VDD)
unnamed: C18.1, FB2.2, Y1.7 (VDDO)
unnamed: C48.1, Y1.2 (XA)
SCL: U2.13 (SCL), Y1.4 (SCL); also elsewhere on the board
SD: U2.6 (SDOUT); also elsewhere on the board
SDA: U2.12 (SDA), Y1.5 (SDA); also elsewhere on the board
WS: U2.8 (FSYNC); also elsewhere on the board

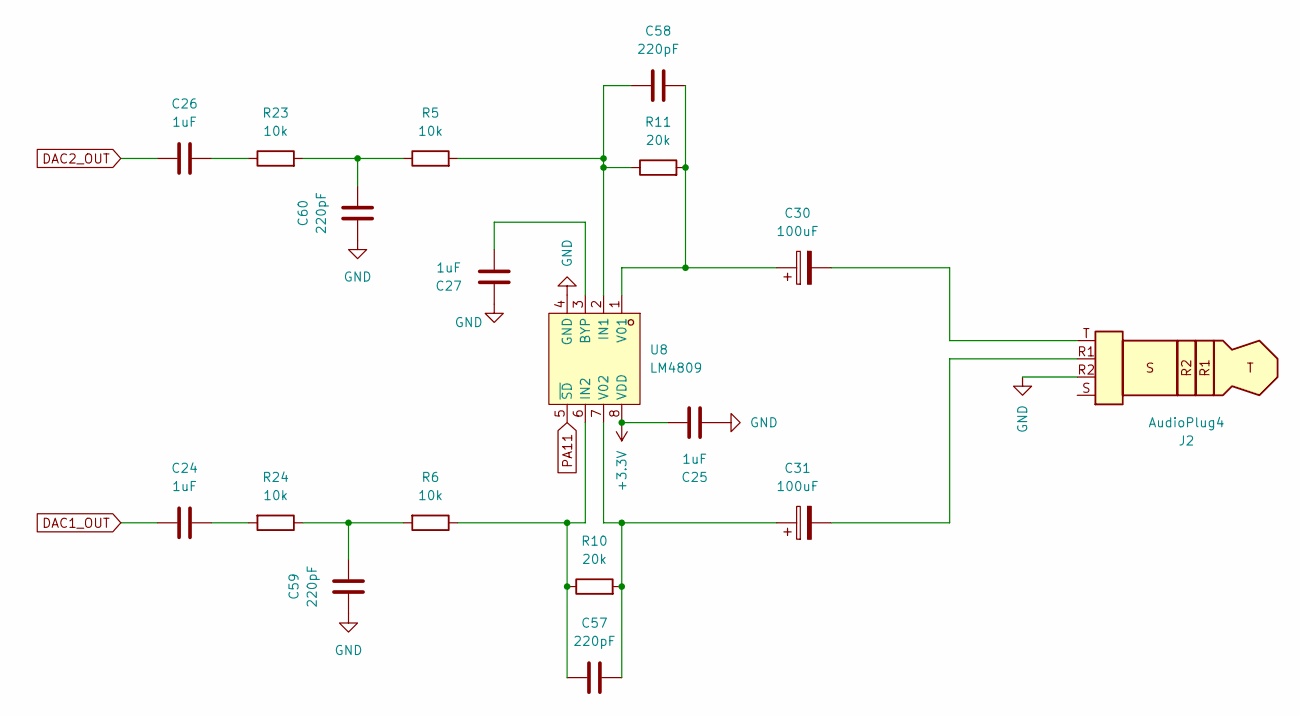
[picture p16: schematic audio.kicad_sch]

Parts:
C24, C25, C26, C27: 1uF; C_0805_2012Metric_Pad1.18x1.45mm_HandSolder
C30, C31: 100uF; CP_EIA-3528-15_AVX-H_HandSolder
C57, C58, C59, C60: 220pF; C_0805_2012Metric_Pad1.18x1.45mm_HandSolder
J2: AudioPlug4; Jack_3.5mm_KoreanHropartsElec_PJ-320D-4A_Horizontal
R5, R6, R23, R24: 10k; R_0805_2012Metric_Pad1.20x1.40mm_HandSolder
R10, R11: 20k; R_0805_2012Metric_Pad1.20x1.40mm_HandSolder
U8: LM4809; MSOP-8_L3.0-W3.0-P0.65-LS4.9-BL; LCSC Part C5125075

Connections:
+3.3V: C25.2, U8.8 (VDD); also elsewhere on the board
DAC1_OUT: C24.2; also elsewhere on the board
DAC2_OUT: C26.2; also elsewhere on the board
GND: C25.1, C27.2, C59.2, C60.2, J2.R2, U8.4 (GND); also elsewhere on the board
unnamed: C24.1, R24.2
unnamed: C26.1, R23.1
unnamed: C30.2, J2.T
unnamed: C31.2, J2.R1
unnamed: C59.1, R6.2, R24.1
unnamed: C60.1, R5.1, R23.2
unnamed: C27.1, U8.3 (BYP)
unnamed: C58.2, R5.2, R11.1, U8.2 (IN1)
unnamed: C57.2, R6.1, R10.1, U8.6 (IN2)
unnamed: C30.1, C58.1, R11.2, U8.1 (V01)
unnamed: C31.1, C57.1, R10.2, U8.7 (V02)
PA11: U8.5 (~SD); also elsewhere on the board

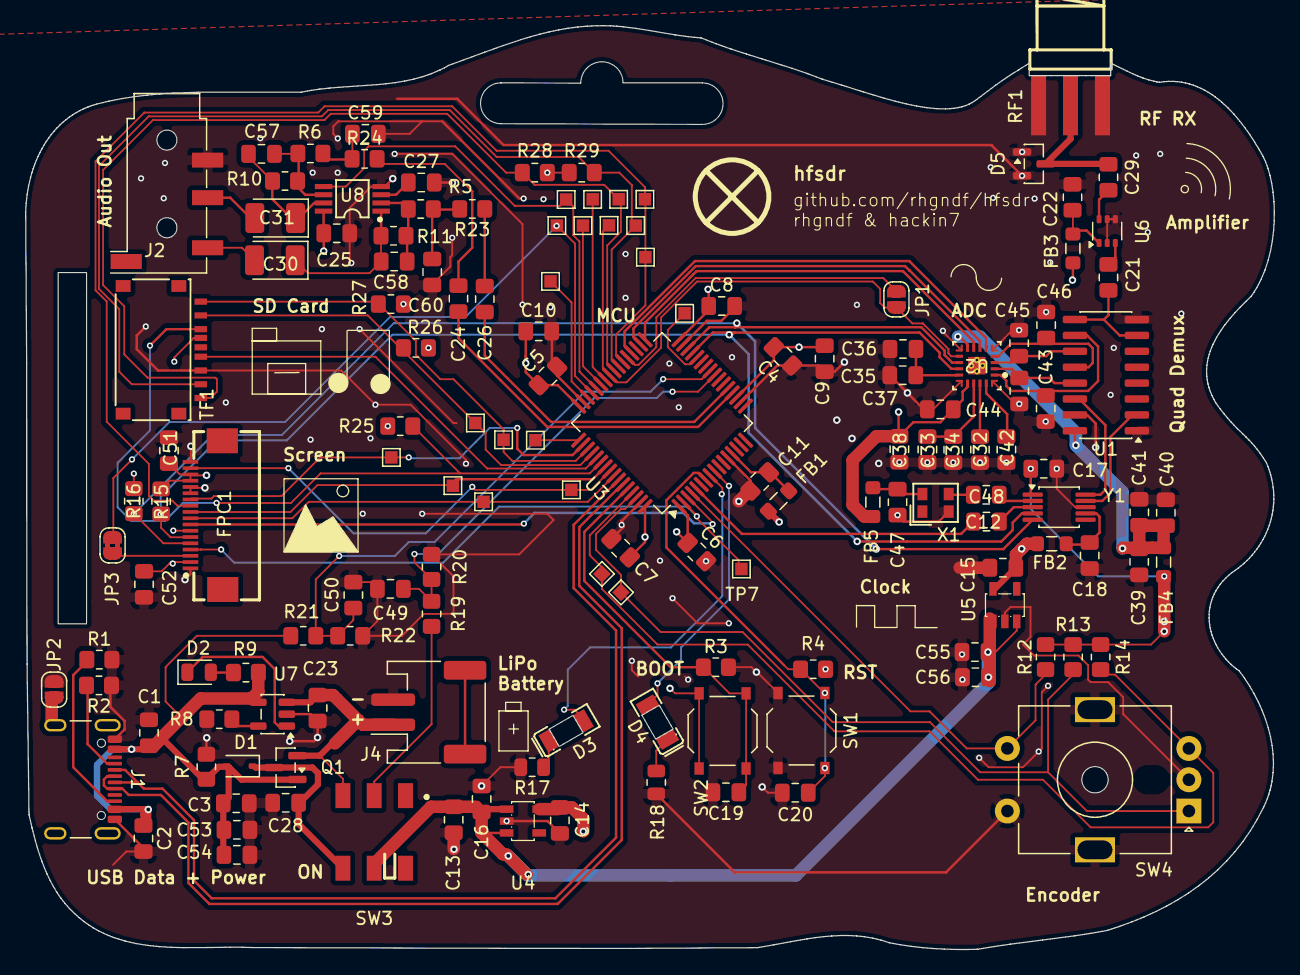
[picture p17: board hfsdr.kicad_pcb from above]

Board: 4 copper layers, 99.8 x 73.8 mm, 144 parts (0 on the bottom side), 90 nets.

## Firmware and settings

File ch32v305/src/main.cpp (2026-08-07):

/********************************** (C) COPYRIGHT *******************************
* File Name          : main.c
* Author             : WCH
* Version            : V1.0.0
* Date               : 2021/06/06
* Description        : Main program body.
*********************************************************************************
* Copyright (c) 2021 Nanjing Qinheng Microelectronics Co., Ltd.
* Attention: This software (modified or not) and binary are used for 
* microcontroller manufactured by Nanjing Qinheng Microelectronics.
*******************************************************************************/

/*
 *@Note
 GPIO routine:
 PA0 push-pull output.

*/
#include "debug.h"
#include "main.h"
#include <stddef.h>

extern "C" {
#include "FreeRTOS.h"
#include "task.h"

#include "hw/pinout.h"
#include "hw/dac.h"
#include "hw/encoder.h"
#include "hw/display/st7789.h"
#include "hw/display/cst328.h"

#include "hw/i2c.h"
#include "hw/tlv320adc6120.h"
#include "hw/si5351.h"
#include "hw/i2s.h"
#include "hw/usb.h"
#include "hw/watchdog.h"
#include "hw/adc.h"
#include "hw/rtc.h"
#include "hw/trng.h"
#include "feature/blinky/blinky.h"
#include "demod/demod.h"
#include "ui/ui.h"
#include "ui/hw_state.h"
}

#include "feature/iq_calibration/iq_calibration.h"
#include "demod/rds.h"
#include "recording.h"
#include "utils/utils.h"
#include "freertos/task_stacks.h"


constexpr uint32_t InitialCalibrationFreq = 144020000U;
constexpr uint32_t InitialFMFreq = 92400000U;
static void Boot_Display_InitLandscape(void);

static hardware_rev_t s_hardware_rev = HARDWARE_REV_UNKNOWN;
static StaticTask_t s_i2s_task_tcb;
static StackType_t s_i2s_task_stack[I2S_TASK_STACK_WORDS]
    __attribute__((aligned(portBYTE_ALIGNMENT)));
static StaticTask_t s_usb_task_tcb;
static StackType_t s_usb_task_stack[USB_TASK_STACK_WORDS]
    __attribute__((aligned(portBYTE_ALIGNMENT)));
static StaticTask_t s_application_task_tcb;
static StackType_t s_application_task_stack[APP_TASK_STACK_WORDS]
    __attribute__((aligned(portBYTE_ALIGNMENT)));
TaskHandle_t g_application_task_handle;

void detect_hardware_rev(void)
{
    GPIO_InitTypeDef gpio{};

    RCC_APB2PeriphClockCmd(RCC_APB2Periph_GPIOB, ENABLE);

    gpio.GPIO_Pin = GPIO_Pin_9;
    gpio.GPIO_Mode = GPIO_Mode_IPD;
    gpio.GPIO_Speed = GPIO_Speed_50MHz;
    GPIO_Init(GPIOB, &gpio);

    Delay_Us(10U);

    s_hardware_rev = (GPIO_ReadInputDataBit(GPIOB, GPIO_Pin_9) != 0U) ? HARDWARE_REV_V2 : HARDWARE_REV_V1;
}

hardware_rev_t get_hardware_rev(void)
{
    return s_hardware_rev;
}

static void SysTick_Report_USB_EverySecond(void)
{
    static uint64_t last_report_tick = 0;
    uint64_t now_tick = SysTick->CNT;

    printf("%d systick_now=0x%lx last=0x%lx %d\r\n",
           25,
           (uint32_t)now_tick,
           (uint32_t)last_report_tick,
           25);

    last_report_tick = now_tick;
}

static void Scan_I2CBus_EverySecond(void)
{
    printf("I2C scan:");

    uint8_t device_count = 0;
    for(uint8_t addr = 0x08U; addr <= 0x77U; ++addr)
    {
        if(i2c_hw_scan_bus_at(addr) == READY)
        {
            ++device_count;
            printf(" 0x%02X", addr);
        }
    }

    if(device_count == 0U)
    {
        printf(" no devices\r\n");
    }
    else
    {
        printf(" (%u)\r\n", device_count);
    }
}

static uint8_t s_tlv320_i2s_report_initialized = 0U;

static void TLV320_I2S_Poll(void)
{
    static uint32_t last_word_count = 0U;
    static uint32_t last_vendor_total_word_count = 0U;
    static uint32_t last_vendor_dropped_word_count = 0U;
    uint32_t words_now = i2s_hw_rx_word_count();
    uint32_t vendor_words_now = usb_hw_vendor_total_words();
    uint32_t vendor_dropped_words_now = usb_hw_vendor_dropped_words();

    if((s_tlv320_i2s_report_initialized == 0U) ||
       (words_now < last_word_count) ||
       (vendor_words_now < last_vendor_total_word_count) ||
       (vendor_dropped_words_now < last_vendor_dropped_word_count))
    {
        last_word_count = words_now;
        last_vendor_total_word_count = vendor_words_now;
        last_vendor_dropped_word_count = vendor_dropped_words_now;
        s_tlv320_i2s_report_initialized = 1U;
    }
    else
    {
        uint32_t words_per_sec = words_now - last_word_count;
        uint32_t frames_per_sec = words_per_sec / 4U;
        uint32_t bytes_per_sec = words_per_sec * (uint32_t)sizeof(uint16_t);
        uint32_t vendor_words_per_sec = vendor_words_now - last_vendor_total_word_count;
        uint32_t vendor_dropped_words_per_sec = vendor_dropped_words_now - last_vendor_dropped_word_count;

        printf("ADC I2S rate: %lu words/s, %lu frames/s, %lu B/s | vendor %lu words/s drop %lu words/s | LO %lu Hz\r\n",
               (unsigned long)words_per_sec,
               (unsigned long)frames_per_sec,
               (unsigned long)bytes_per_sec,
               (unsigned long)vendor_words_per_sec,
               (unsigned long)vendor_dropped_words_per_sec,
               (unsigned long)hw_state_get_frequency());

        last_word_count = words_now;
        last_vendor_total_word_count = vendor_words_now;
        last_vendor_dropped_word_count = vendor_dropped_words_now;
    }
}

static uint8_t s_i2s_bitslip_check = 1U;
static uint8_t s_i2s_bitslip_sync_dots = 0U;
static uint32_t s_i2s_bitslip_checked_word_count = 0U;

static void Boot_Display_InitLandscape(void)
{
    ST7789_SetRotation(3U);
    ST7789_VerticalScrollDisable();
    ST7789_Fill_Color(BLACK);
}

static void Draw_I2S_Syncing_Status(void)
{
    constexpr const char *sync_text[] = {
        "Syncing   ",
        "Syncing.  ",
        "Syncing.. ",
        "Syncing..."
    };

    ST7789_WriteString(0U, 5U, sync_text[s_i2s_bitslip_sync_dots], Font_11x18, WHITE, BLACK);
}

static void TLV320_I2S_CheckBitslip(void)
{
    if(s_i2s_bitslip_check == 0U)
    {
        return;
    }


    static uint32_t i2s_last_rx_word = 0;
    uint32_t i2s_cur_rx_word = i2s_hw_rx_word_count();
    if (i2s_last_rx_word == i2s_cur_rx_word) {
        return;
    }
    i2s_last_rx_word = i2s_cur_rx_word;

    bool i2s_reset_needed = i2s_needs_reset();
    if(i2s_reset_needed)
    {
        s_i2s_bitslip_checked_word_count = 0U;
        s_i2s_bitslip_sync_dots = (uint8_t)((s_i2s_bitslip_sync_dots + 1U) & 3U);
        Draw_I2S_Syncing_Status();
        printf("bitslipped, resetting\n");
        i2s_hw_enable(DISABLE);
        i2s_hw_deinit();
        // Random wait
        uint32_t wait_amt = trng_hw_read_u32()%1000000;
        while(wait_amt--) {
            asm volatile("nop");
        }
        i2s_hw_init();
        i2s_hw_enable(ENABLE);
        s_tlv320_i2s_report_initialized = 0U;
        s_i2s_bitslip_check = 1U;
        return;
    }

    uint32_t word_count = i2s_hw_rx_word_count();
    if(word_count == s_i2s_bitslip_checked_word_count)
    {
        return;
    }

    s_i2s_bitslip_checked_word_count = word_count;
    s_i2s_bitslip_check = 0U;
}

static void ADC_Poll(void)
{
    uint32_t vdda = adc_hw_vdda_mv();
    uint16_t batt_raw = adc_hw_read_batt_raw();
    uint16_t vbus_raw = adc_hw_read_vbus_raw();
    uint16_t temp_raw = adc_hw_read_temp_raw();

    uint32_t batt_mv = (uint32_t)batt_raw * vdda * 2U / 4096U;
    uint32_t vbus_mv = (uint32_t)vbus_raw * vdda * 2U / 4096U;
    uint32_t temp_mv = (uint32_t)temp_raw * vdda / 4096U;
    int32_t temp_c = TempSensor_Volt_To_Temper((int32_t)temp_mv);

    printf("BATT: raw=%u %lu.%03lu V | VBUS: raw=%u %lu.%03lu V | TEMP: raw=%u %ld C\r\n",
           batt_raw, (unsigned long)(batt_mv / 1000U), (unsigned long)(batt_mv % 1000U),
           vbus_raw, (unsigned long)(vbus_mv / 1000U), (unsigned long)(vbus_mv % 1000U),
           temp_raw, (long)temp_c);
}

static void Application_Task(void *parameters)
{
    (void)parameters;

    //rtc_init();
    detect_hardware_rev();
    
    printf("SystemClk:%ld\r\n", SystemCoreClock);
    printf( "ChipID:%08lx\r\n", DBGMCU_GetCHIPID() );
    printf("Hardware rev:v%u\r\n", (unsigned int)get_hardware_rev());
    
    printf("ST7789 init\r\n");
    ST7789_Init();
    Boot_Display_InitLandscape();

    i2c_hw_init();
    si5351_init();
    
    if(si5351_hw_clk0_set_freq_hz(InitialCalibrationFreq))
    {
        printf("Si5351: LO CLK0/CLK1 = %lu Hz, CLK1 = +90 deg\r\n",
               (unsigned long)InitialCalibrationFreq);
    }
    else
    {
        printf("Si5351: LO program failed (I2C 0x60)\r\n");
    }

    if(tlv320adc6120_hw_init() == READY)
    {
        printf("TLV320ADC6120: I2C 0x4E, I2S controller 24-bit CH1+CH2, expects 24 MHz MCLK\r\n");
        GPIO_WriteBit(LED2_GPIO_PORT, LED2_GPIO_PIN, Bit_SET);
    }
    else
    {
        printf("TLV320ADC6120: I2C init failed (check wiring / AVDD AREG define / 24 MHz MCLK)\r\n");
    }

    if(cst328_hw_init() == READY)
    {
        printf("CST328: touch controller ready (I2C 0x1A)\r\n");
    }
    else
    {
        printf("CST328: init failed, touchscreen not present\r\n");
    }

    i2s_hw_init();
    i2s_hw_enable(ENABLE);

    adc_hw_init();
    dac_hw_init();
    encoder_init();
    demod_init();
    printf("Demod audio out: enabled (WBFM/NBFM/AM/USB/LSB to DAC)\r\n");

    blinky_init();

    PeriodicTrigger I2SPoll{1000U, TLV320_I2S_Poll};
    PeriodicTrigger I2CBusScan{1000U, Scan_I2CBus_EverySecond};
    PeriodicTrigger SysTickReportUSB{1000U, SysTick_Report_USB_EverySecond};
    PeriodicTrigger ADCPoll{1000U, ADC_Poll};
    si5351_hw_clk0_set_freq_hz(InitialCalibrationFreq);

    trng_hw_init();
    (void)tlv320adc6120_ch1_mute(true);
    while(s_i2s_bitslip_check)
    {
        portYIELD();
        TLV320_I2S_CheckBitslip();
    }
    (void)tlv320adc6120_ch1_mute(false);
    trng_hw_deinit();
    
    ST7789_Fill_Color(BLACK);
    i2s_sync_check_disable();

    /*(void)tlv320adc6120_hw_set_ch_gain_db_x2(-100);
    while(iq_calibration_run())
    {
        iq_calibration_display();
    }*/

    (void)tlv320adc6120_hw_set_ch_gain_db_x2(0);
    si5351_hw_clk0_set_freq_hz(InitialFMFreq);

    hw_state_publish_boot_state(InitialFMFreq,
                                InitialFMFreq,
                                READY,
                                0);

    UI_Init();
    watchdog_kick();

    while(1)
    {
        I2SPoll();
        //I2CBusScan();
        //SysTickReportUSB();
        UI_Draw();
        //ADCPoll();
        //cst328_hw_poll();
        blinky_task();
        //demod::rds_poll();
        watchdog_kick();
        vTaskDelay(pdMS_TO_TICKS(2));
    }
}

/*********************************************************************
 * @fn      main
 *
 * @brief   Configure the scheduler and create all statically allocated tasks.
 *
 * @return  none
 */
int main(void)
{
    NVIC_PriorityGroupConfig(NVIC_PriorityGroup_2);
    SystemCoreClockUpdate();
    configASSERT(SystemCoreClock == configCPU_CLOCK_HZ);
    Delay_Init();

    TaskHandle_t i2s_task_handle =
        xTaskCreateStatic(i2s_task,
                          "i2s",
                          I2S_TASK_STACK_WORDS,
                          nullptr,
                          3U,
                          s_i2s_task_stack,
                          &s_i2s_task_tcb);
    configASSERT(i2s_task_handle != nullptr);

    TaskHandle_t usb_task_handle =
        xTaskCreateStatic(usb_task,
                          "usb",
                          USB_TASK_STACK_WORDS,
                          nullptr,
                          2U,
                          s_usb_task_stack,
                          &s_usb_task_tcb);
    configASSERT(usb_task_handle != nullptr);

    hw_state_init();
    recording_init();

    g_application_task_handle =
        xTaskCreateStatic(Application_Task,
                          "application",
                          APP_TASK_STACK_WORDS,
                          nullptr,
                          1U,
                          s_application_task_stack,
                          &s_application_task_tcb);
    configASSERT(g_application_task_handle != nullptr);

    vTaskStartScheduler();
    configASSERT(false);
    for(;;)
    {
    }
}

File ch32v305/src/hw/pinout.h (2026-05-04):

#ifndef PINOUT_H
#define PINOUT_H

#include "ch32v30x.h"

// --- nanoCH32V305 --------------------------------------
/* Global define */
#define LED_GPIO_PORT      GPIOA
#define LED_GPIO_PIN       GPIO_Pin_3

// --- hfsdr badge ---------------------------------------
/* LEDs */
#define LED1_GPIO_PORT     GPIOC
#define LED1_GPIO_PIN      GPIO_Pin_0
#define LED2_GPIO_PORT     GPIOC
#define LED2_GPIO_PIN      GPIO_Pin_1

/* DAC */
#define DAC1_OUT_GPIO_PORT GPIOA
#define DAC1_OUT_GPIO_PIN  GPIO_Pin_4
#define DAC2_OUT_GPIO_PORT GPIOA
#define DAC2_OUT_GPIO_PIN  GPIO_Pin_5
#define DAC_AMP_SD_GPIO_PORT GPIOA
#define DAC_AMP_SD_GPIO_PIN  GPIO_Pin_11

/* Encoder */
#define ENC_A_GPIO_PORT    GPIOB
#define ENC_A_GPIO_PIN     GPIO_Pin_8
#define ENC_B_GPIO_PORT    GPIOB
#define ENC_B_GPIO_PIN     GPIO_Pin_9
#define ENC_BTN_GPIO_PORT  GPIOC
#define ENC_BTN_GPIO_PIN   GPIO_Pin_15

/* ADC sense */
#define BATT_ADC_GPIO_PORT GPIOC
#define BATT_ADC_GPIO_PIN  GPIO_Pin_4
#define VBUS_ADC_GPIO_PORT GPIOC
#define VBUS_ADC_GPIO_PIN  GPIO_Pin_5

/* I2S - ADC */
#define I2S_WS_GPIO_PORT   GPIOB
#define I2S_WS_GPIO_PIN    GPIO_Pin_12
#define I2S_CK_GPIO_PORT   GPIOB
#define I2S_CK_GPIO_PIN    GPIO_Pin_13
#define I2S_SD_GPIO_PORT   GPIOB
#define I2S_SD_GPIO_PIN    GPIO_Pin_15
#define I2S_MCK_GPIO_PORT  GPIOC
#define I2S_MCK_GPIO_PIN   GPIO_Pin_6

/* SPI3 - Screen SCK/MOSI on PB3/PB5 */
#define SPI3_SCL_SCK_GPIO_PORT  GPIOB
#define SPI3_SCL_SCK_GPIO_PIN   GPIO_Pin_3
#define SPI3_SDA_MOSI_GPIO_PORT GPIOB
#define SPI3_SDA_MOSI_GPIO_PIN  GPIO_Pin_5

/* ST7789 + touch: command vs SPI data is RS (register select), not a separate DC pin. */
/* ST7789 reset: active-low (drive low to reset, high for normal run). */
#define ST7789_RST_GPIO_PORT  GPIOC
#define ST7789_RST_GPIO_PIN   GPIO_Pin_14
/* CST328 touch panel reset (active-low): PC13 */
#define TP_RST_GPIO_PORT      GPIOC
#define TP_RST_GPIO_PIN       GPIO_Pin_13
/* CST328 touch panel IRQ (open-drain output from chip, active-low): PA12 */
#define TP_INT_GPIO_PORT      GPIOA
#define TP_INT_GPIO_PIN       GPIO_Pin_12
/* Previous pinouts:
 * #define ST7789_CS_GPIO_PORT   GPIOD
 * #define ST7789_CS_GPIO_PIN    GPIO_Pin_2
 * #define ST7789_RS_GPIO_PORT   GPIOC
 * #define ST7789_RS_GPIO_PIN    GPIO_Pin_12
 */
#define ST7789_CS_GPIO_PORT   GPIOC
#define ST7789_CS_GPIO_PIN    GPIO_Pin_7
#define ST7789_RS_GPIO_PORT   GPIOA
#define ST7789_RS_GPIO_PIN    GPIO_Pin_15
#define ST7789_LEDK_GPIO_PORT GPIOB
#define ST7789_LEDK_GPIO_PIN  GPIO_Pin_4

/* I2C - Touchscreen, ADC (RS also drives LCD register select on the shared flex / routing) */
#define I2C_SCL_GPIO_PORT   GPIOB
#define I2C_SCL_GPIO_PIN    GPIO_Pin_10
#define I2C_SDA_GPIO_PORT   GPIOB
#define I2C_SDA_GPIO_PIN    GPIO_Pin_11

/* SDIO - SD Card */
#define SDIO_D0_GPIO_PORT   GPIOC
#define SDIO_D0_GPIO_PIN    GPIO_Pin_8
#define SDIO_D1_GPIO_PORT   GPIOC
#define SDIO_D1_GPIO_PIN    GPIO_Pin_9
#define SDIO_D2_GPIO_PORT   GPIOC
#define SDIO_D2_GPIO_PIN    GPIO_Pin_10
#define SDIO_D3_GPIO_PORT   GPIOC
#define SDIO_D3_GPIO_PIN    GPIO_Pin_11
#define SDIO_CLK_GPIO_PORT  GPIOC
#define SDIO_CLK_GPIO_PIN   GPIO_Pin_12
#define SDIO_CMD_GPIO_PORT  GPIOD
#define SDIO_CMD_GPIO_PIN   GPIO_Pin_2

#endif

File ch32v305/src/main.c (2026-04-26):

/********************************** (C) COPYRIGHT *******************************
* File Name          : main.c
* Author             : WCH
* Version            : V1.0.0
* Date               : 2021/06/06
* Description        : Main program body.
*********************************************************************************
* Copyright (c) 2021 Nanjing Qinheng Microelectronics Co., Ltd.
* Attention: This software (modified or not) and binary are used for 
* microcontroller manufactured by Nanjing Qinheng Microelectronics.
*******************************************************************************/

/*
 *@Note
 GPIO routine:
 PA0 push-pull output.

*/


#include "debug.h"
#include <stddef.h>

#include "hw/pinout.h"
#include "hw/dac_hw.h"
#include "hw/encoder.h"
#include "hw/spi_manual.h"
#include "hw/display/st7789.h"

#include "hw/i2c_hw.h"
#include "hw/tlv320adc6120_hw.h"
#include "hw/si5351_hw.h"
#include "hw/i2s_hw.h"
#include "hw/usb_hw.h"
#include "hw/watchdog.h"
#include "feature/blinky/blinky.h"
#include "feature/fm_audio_out/fm_audio_out.h"
#include "ui/fft.h"

#include "tusb.h"

/*********************************************************************
 * @fn      GPIO_Toggle_INIT
 *
 * @brief   Initializes GPIOA.0
 *
 * @return  none
 */
void GPIO_Toggle_INIT(void)
{
    blinky_gpio_init();
}

[[maybe_unused]] static void TP_Reset_Pin_On(void)
{
    /* TP/LCD reset net is active-low: drive high to release ("on"). */
    RCC_APB2PeriphClockCmd(RCC_APB2Periph_GPIOC, ENABLE);
    GPIO_InitTypeDef gpio_init = {0};
    gpio_init.GPIO_Pin = TP_RST_GPIO_PIN;
    gpio_init.GPIO_Mode = GPIO_Mode_Out_PP;
    gpio_init.GPIO_Speed = GPIO_Speed_50MHz;
    GPIO_Init(TP_RST_GPIO_PORT, &gpio_init);
    GPIO_WriteBit(TP_RST_GPIO_PORT, TP_RST_GPIO_PIN, Bit_SET);
}

[[maybe_unused]] static void TP_Reset_Pin_Off(void)
{
    /* TP/LCD reset net is active-low: drive high to release ("on"). */
    RCC_APB2PeriphClockCmd(RCC_APB2Periph_GPIOC, ENABLE);
    GPIO_InitTypeDef gpio_init = {0};
    gpio_init.GPIO_Pin = TP_RST_GPIO_PIN;
    gpio_init.GPIO_Mode = GPIO_Mode_Out_PP;
    gpio_init.GPIO_Speed = GPIO_Speed_50MHz;
    GPIO_Init(TP_RST_GPIO_PORT, &gpio_init);
    GPIO_WriteBit(TP_RST_GPIO_PORT, TP_RST_GPIO_PIN, Bit_RESET);
}


[[maybe_unused]] static void SysTick_Report_USB_EverySecond(void)
{
    static uint64_t last_report_tick = 0;
    static uint8_t initialized = 0;
    uint64_t now_tick = SysTick->CNT;
    uint64_t report_period_ticks = (uint64_t)SystemCoreClock / 2;

    if(report_period_ticks == 0U)
    {
        report_period_ticks = 1U;
    }

    if(initialized == 0U)
    {
        last_report_tick = now_tick;
        initialized = 1U;
        return;
    }

    if((now_tick - last_report_tick) < report_period_ticks)
    {
        return;
    }

    printf("%d systick_now=0x%lx last=0x%lx %d\r\n",
           25,
           (uint32_t)now_tick,
           (uint32_t)last_report_tick,
           25);

    last_report_tick = now_tick;
}

[[maybe_unused]] static void Scan_I2CBus_EverySecond(void)
{
    static uint64_t last_scan_tick = 0;
    static uint8_t initialized = 0;
    uint64_t now_tick = SysTick->CNT;
    uint64_t scan_period_ticks = (uint64_t)SystemCoreClock;

    if(scan_period_ticks == 0U)
    {
        scan_period_ticks = 1U;
    }

    if(initialized == 0U)
    {
        last_scan_tick = now_tick;
        initialized = 1U;
        return;
    }

    if((now_tick - last_scan_tick) < scan_period_ticks)
    {
        return;
    }

    printf("I2C scan:");

    uint8_t device_count = 0;
    for(uint8_t addr = 0x08U; addr <= 0x77U; ++addr)
    {
        if(i2c_hw_scan_bus_at(addr) == READY)
        {
            ++device_count;
            printf(" 0x%02X", addr);
        }
    }

    if(device_count == 0U)
    {
        printf(" no devices\r\n");
    }
    else
    {
        printf(" (%u)\r\n", device_count);
    }

    last_scan_tick = now_tick;
}

/*********************************************************************
 * TLV320ADC6120 I2S capture (CH1/CH2)
 *
 * In the current 24-bit I2S mode, the CH32 peripheral uses 32-bit channel
 * frames, so each stereo frame arrives as four 16-bit DMA words.
 * SPI2 RX DMA runs in circular mode; DMA HT/TC interrupts count those words.
 * Report the incoming data rate once per second.
 *********************************************************************/
static uint8_t s_tlv320_i2s_report_initialized = 0U;
static uint64_t ticks_from_ms(uint32_t ms);
static void Encoder_ReportRotation(void);

static void TLV320_I2S_Poll(void)
{
    static uint64_t last_report_tick = 0U;
    static uint32_t last_word_count = 0U;
    static uint32_t last_vendor_total_word_count = 0U;
    static uint32_t last_vendor_dropped_word_count = 0U;
    uint64_t now_tick = SysTick->CNT;
    uint32_t words_now = i2s_hw_rx_word_count();
    uint32_t vendor_words_now = usb_hw_vendor_total_words();
    uint32_t vendor_dropped_words_now = usb_hw_vendor_dropped_words();

    if((s_tlv320_i2s_report_initialized == 0U) ||
       (words_now < last_word_count) ||
       (vendor_words_now < last_vendor_total_word_count) ||
       (vendor_dropped_words_now < last_vendor_dropped_word_count))
    {
        last_report_tick = now_tick;
        last_word_count = words_now;
        last_vendor_total_word_count = vendor_words_now;
        last_vendor_dropped_word_count = vendor_dropped_words_now;
        s_tlv320_i2s_report_initialized = 1U;
    }
    else
    {
        uint64_t elapsed_ticks = now_tick - last_report_tick;
        if(elapsed_ticks >= (uint64_t)SystemCoreClock)
        {
            uint32_t words_per_sec = (uint32_t)((((uint64_t)(words_now - last_word_count)) * (uint64_t)SystemCoreClock) / elapsed_ticks);
            uint32_t frames_per_sec = words_per_sec / 4U;
            uint32_t bytes_per_sec = words_per_sec * (uint32_t)sizeof(uint16_t);
            uint32_t vendor_words_per_sec = (uint32_t)((((uint64_t)(vendor_words_now - last_vendor_total_word_count)) * (uint64_t)SystemCoreClock) / elapsed_ticks);
            uint32_t vendor_dropped_words_per_sec = (uint32_t)((((uint64_t)(vendor_dropped_words_now - last_vendor_dropped_word_count)) * (uint64_t)SystemCoreClock) / elapsed_ticks);

            printf("ADC I2S rate: %lu words/s, %lu frames/s, %lu B/s | vendor %lu words/s drop %lu words/s | LO %lu Hz\r\n",
                   (unsigned long)words_per_sec,
                   (unsigned long)frames_per_sec,
                   (unsigned long)bytes_per_sec,
                   (unsigned long)vendor_words_per_sec,
                   (unsigned long)vendor_dropped_words_per_sec,
                   (unsigned long)si5351_hw_clk0_get_freq_hz());

            last_word_count = words_now;
            last_vendor_total_word_count = vendor_words_now;
            last_vendor_dropped_word_count = vendor_dropped_words_now;
            last_report_tick = now_tick;
        }
    }
}
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

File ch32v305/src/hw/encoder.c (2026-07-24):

#include "encoder.h"

#include "freertos/port_isr.h"
#include "hw/pinout.h"
#include "ui/ui.h"

#include <stdatomic.h>

#include "ch32v30x_exti.h"
#include "ch32v30x_gpio.h"
#include "ch32v30x_misc.h"
#include "ch32v30x_rcc.h"
#include "ch32v30x_tim.h"

#define ENCODER_TIMER             TIM10
#define ENCODER_TIMER_PERIPH      RCC_APB2Periph_TIM10
#define ENCODER_GPIO_PERIPH       RCC_APB2Periph_GPIOB
#define ENCODER_INPUT_FILTER      0x0FU
#define ENCODER_COUNTER_MIDPOINT  0x8000U
#define ENCODER_COUNTS_PER_DETENT 4
#define ENCODER_BUTTON_DEBOUNCE_MS 30U
#define ENCODER_BUTTON_LONG_PRESS_MS 1000U
#define ENCODER_BUTTON_EXTI_LINE  EXTI_Line15
#define ENCODER_BUTTON_EXTI_IRQn  EXTI15_10_IRQn

/* Encoder switch: IPU, low when pressed (tied to GND). */
#define ENC_BTN_PRESSED(st) ((st) == 0U)

typedef enum
{
    ENCODER_BUTTON_STATE_IDLE = 0,
    ENCODER_BUTTON_STATE_PRESSED,
} encoder_button_state_t;

static volatile uint16_t s_encoder_last_counter = ENCODER_COUNTER_MIDPOINT;
static atomic_int_fast32_t s_encoder_pending_raw_delta = 0;
static volatile int32_t s_encoder_raw_position = 0;
static int16_t s_encoder_detent_remainder = 0;
static volatile encoder_button_state_t s_button_state = ENCODER_BUTTON_STATE_IDLE;
static volatile uint64_t s_button_press_start_tick = 0U;
static volatile uint64_t s_button_debounce_ticks;
static volatile uint64_t s_button_long_press_ticks;

static uint64_t encoder_ticks_from_ms(uint32_t ms)
{
    uint64_t ticks = ((uint64_t)SystemCoreClock * (uint64_t)ms) / 1000ULL;

    return (ticks == 0U) ? 1U : ticks;
}

static int16_t encoder_sync_delta(void)
{
    uint16_t now = TIM_GetCounter(ENCODER_TIMER);
    int16_t delta = (int16_t)(now - s_encoder_last_counter);

    if(delta != 0)
    {
        s_encoder_last_counter = now;
        s_encoder_raw_position += delta;
    }

    return delta;
}

PORT_ISR_BODY(EXTI15_10_IRQHandler)
{
    if(EXTI_GetITStatus(ENCODER_BUTTON_EXTI_LINE) == RESET)
    {
        return;
    }

    EXTI_ClearITPendingBit(ENCODER_BUTTON_EXTI_LINE);

    uint8_t raw_state = (uint8_t)GPIO_ReadInputDataBit(ENC_BTN_GPIO_PORT, ENC_BTN_GPIO_PIN);
    uint64_t now_tick = SysTick->CNT;

    if(ENC_BTN_PRESSED(raw_state))
    {
        if(s_button_state == ENCODER_BUTTON_STATE_IDLE)
        {
            s_button_press_start_tick = now_tick;
            s_button_state = ENCODER_BUTTON_STATE_PRESSED;
        }
        return;
    }

    if(s_button_state != ENCODER_BUTTON_STATE_PRESSED)
    {
        return;
    }

    uint64_t press_ticks = now_tick - s_button_press_start_tick;
    s_button_state = ENCODER_BUTTON_STATE_IDLE;

    if(press_ticks < s_button_debounce_ticks)
    {
        return;
    }

    if(press_ticks < s_button_long_press_ticks)
    {
        ui_handle_button_press();
    }
    else
    {
        ui_handle_button_long_press();
    }
}

PORT_ISR_BODY(TIM10_CC_IRQHandler)
{
    uint8_t have_cc1 = (uint8_t)(TIM_GetITStatus(ENCODER_TIMER, TIM_IT_CC1) != RESET);
    uint8_t have_cc2 = (uint8_t)(TIM_GetITStatus(ENCODER_TIMER, TIM_IT_CC2) != RESET);

    if((have_cc1 == 0U) && (have_cc2 == 0U))
    {
        return;
    }

    if(have_cc1 != 0U)
    {
        TIM_ClearITPendingBit(ENCODER_TIMER, TIM_IT_CC1);
    }

    if(have_cc2 != 0U)
    {
        TIM_ClearITPendingBit(ENCODER_TIMER, TIM_IT_CC2);
    }

    int_fast32_t delta = encoder_sync_delta();
    if(delta != 0)
    {
        atomic_fetch_add_explicit(&s_encoder_pending_raw_delta, delta, memory_order_relaxed);
    }
}

void encoder_init(void)
{
    GPIO_InitTypeDef gpio = {0};

    RCC_APB2PeriphClockCmd(ENCODER_GPIO_PERIPH |
                          ENCODER_TIMER_PERIPH |
                          RCC_APB2Periph_GPIOC |
                          RCC_APB2Periph_AFIO,
                          ENABLE);

    gpio.GPIO_Pin = ENC_A_GPIO_PIN | ENC_B_GPIO_PIN;
    gpio.GPIO_Mode = GPIO_Mode_IN_FLOATING;
    gpio.GPIO_Speed = GPIO_Speed_50MHz;
    GPIO_Init(ENC_A_GPIO_PORT, &gpio);

    gpio.GPIO_Pin = ENC_BTN_GPIO_PIN;
    gpio.GPIO_Mode = GPIO_Mode_IPU;
    GPIO_Init(ENC_BTN_GPIO_PORT, &gpio);

    TIM_DeInit(ENCODER_TIMER);

    TIM_TimeBaseInitTypeDef tim = {0};
    TIM_TimeBaseStructInit(&tim);
    tim.TIM_Prescaler = 0U;
    tim.TIM_Period = 0xFFFFU;
    tim.TIM_ClockDivision = TIM_CKD_DIV1;
    tim.TIM_CounterMode = TIM_CounterMode_Up;
    TIM_TimeBaseInit(ENCODER_TIMER, &tim);

    TIM_ICInitTypeDef ic = {0};
    TIM_ICStructInit(&ic);
    ic.TIM_ICPolarity = TIM_ICPolarity_Falling;
    ic.TIM_ICSelection = TIM_ICSelection_DirectTI;
    ic.TIM_ICPrescaler = TIM_ICPSC_DIV1;
    ic.TIM_ICFilter = ENCODER_INPUT_FILTER;

    ic.TIM_Channel = TIM_Channel_1;
    TIM_ICInit(ENCODER_TIMER, &ic);

    ic.TIM_Channel = TIM_Channel_2;
    TIM_ICInit(ENCODER_TIMER, &ic);

    TIM_EncoderInterfaceConfig(ENCODER_TIMER,
                               TIM_EncoderMode_TI12,
                               TIM_ICPolarity_Falling,
                               TIM_ICPolarity_Rising);

    TIM_SetAutoreload(ENCODER_TIMER, 0xFFFFU);
    TIM_SetCounter(ENCODER_TIMER, ENCODER_COUNTER_MIDPOINT);
    TIM_ITConfig(ENCODER_TIMER, TIM_IT_CC1 | TIM_IT_CC2, ENABLE);
    TIM_ClearFlag(ENCODER_TIMER, TIM_FLAG_Update);

    NVIC_InitTypeDef encoder_nvic = {0};
    encoder_nvic.NVIC_IRQChannel = TIM10_CC_IRQn;
    encoder_nvic.NVIC_IRQChannelPreemptionPriority = 2;
    encoder_nvic.NVIC_IRQChannelSubPriority = 0;
    encoder_nvic.NVIC_IRQChannelCmd = ENABLE;
    NVIC_Init(&encoder_nvic);

    TIM_Cmd(ENCODER_TIMER, ENABLE);

    s_encoder_last_counter = ENCODER_COUNTER_MIDPOINT;
    atomic_store_explicit(&s_encoder_pending_raw_delta, 0, memory_order_relaxed);
    s_encoder_raw_position = 0;
    s_encoder_detent_remainder = 0;
    s_button_state = ENCODER_BUTTON_STATE_IDLE;
    s_button_press_start_tick = 0U;
    s_button_debounce_ticks = encoder_ticks_from_ms(ENCODER_BUTTON_DEBOUNCE_MS);
    s_button_long_press_ticks = encoder_ticks_from_ms(ENCODER_BUTTON_LONG_PRESS_MS);

    GPIO_EXTILineConfig(GPIO_PortSourceGPIOC, GPIO_PinSource15);

    EXTI_InitTypeDef button_exti = {
        .EXTI_Line = ENCODER_BUTTON_EXTI_LINE,
        .EXTI_Mode = EXTI_Mode_Interrupt,
        .EXTI_Trigger = EXTI_Trigger_Rising_Falling,
        .EXTI_LineCmd = ENABLE,
    };
    EXTI_Init(&button_exti);
    EXTI_ClearITPendingBit(ENCODER_BUTTON_EXTI_LINE);
    NVIC_ClearPendingIRQ(ENCODER_BUTTON_EXTI_IRQn);

    NVIC_InitTypeDef button_nvic = {0};
    button_nvic.NVIC_IRQChannel = ENCODER_BUTTON_EXTI_IRQn;
    button_nvic.NVIC_IRQChannelPreemptionPriority = 2;
    button_nvic.NVIC_IRQChannelSubPriority = 1;
    button_nvic.NVIC_IRQChannelCmd = ENABLE;
    NVIC_Init(&button_nvic);
}
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

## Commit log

2025-06-21 Add schematic
    [hfsdr.kicad_pcb, hfsdr.kicad_sch]
2025-11-29 Update schematic
    [hfsdr.kicad_pcb, hfsdr.kicad_sch, rf.kicad_sch]
2025-11-29 amp and audio
    [hfsdr.kicad_pcb, hfsdr.kicad_sch, power.kicad_sch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]
2025-12-06 arrange pcb
    [audio.kicad_sch, hfsdr.kicad_pcb, hfsdr.kicad_sch]
2025-12-07 battery switching
    [hfsdr.kicad_pcb, hfsdr.kicad_sch, power.kicad_sch]
2025-12-16 initial component layout
    [audio.kicad_sch, hfsdr.kicad_pcb, hfsdr.kicad_sch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]
2025-12-16 initial screen
    [hfsdr.kicad_pcb, hfsdr.kicad_sch]
2026-02-09 feat: add rough art
    [hfsdr.kicad_pcb, hfsdr.kicad_sch]
2026-02-09 layout + some routing
    [hfsdr.kicad_pcb, hfsdr.kicad_sch, power.kicad_sch]
2026-02-10 feat: routing
    [hfsdr.kicad_pcb, hfsdr.kicad_sch, power.kicad_sch]
2026-02-14 feat: outline
    [hfsdr.kicad_pcb]
2026-02-14 feat: finally got art in
    [hfsdr.kicad_pcb]
2026-02-14 feat: component adjustment position
    [hfsdr.kicad_pcb]
2026-02-14 feat: rough routing and features
    [audio.kicad_sch, hfsdr.kicad_pcb]
2026-02-14 feat: most rules fixed?
    [hfsdr.kicad_pcb, hfsdr.kicad_sch]
2026-02-14 feat: credits
    [hfsdr.kicad_pcb]
2026-02-14 feat: update jlcpcb bom - not complete
    [hfsdr.kicad_pcb]
2026-02-14 feat: hfsdr rough
    [hfsdr.kicad_pcb, hfsdr.kicad_sch, power.kicad_sch]
2026-02-14 fix: minor unconnected pads
    [hfsdr.kicad_pcb]
2026-02-26 feat: add pads + fix adc chip footprint
    [hfsdr.kicad_pcb, hfsdr.kicad_sch, power.kicad_sch]
2026-02-26 feat: add front LEDs
    [hfsdr.kicad_pcb, hfsdr.kicad_sch]
2026-02-27 Fix components
    [hfsdr.kicad_pcb]
2026-02-27 feat: resize board
    [hfsdr.kicad_pcb]
2026-02-27 Production ready
    [hfsdr.kicad_pcb, hfsdr.kicad_sch, power.kicad_sch]
2026-03-05 feat: cursor generated code for i2c i2s and spi
2026-03-05 fix: lmao I chatgpted systick fixes - blink + usb at the same time
    [main.c, pinout.h]
2026-03-05 feat: finally printing stuff
2026-03-07 Update hardware
    [hfsdr.kicad_pcb, hfsdr.kicad_sch, power.kicad_sch]
2026-03-07 Print memory usage and README
2026-03-27 feat: usb enumeration works
    just need change from hse to hsi, because this board no clock
2026-03-28 Make write print to usb serial
2026-03-28 Change to printf
2026-03-29 feat: st7789 spi
2026-03-30 feat: ok SPI is working, or maybe it was already working
2026-03-30 feat: last spi code, i think it'll work, just hardware issue
    [main.c, pinout.h]
2026-03-30 feat: blinky led lights
2026-03-30 feat: 320khz oscillations on si5351 hmm
    [main.c, si5351_hw.c]
2026-03-30 feat: vibed ADC
2026-03-30 static noise fake lmao
    [dac_hw.c, main.c, si5351_hw.c]
2026-03-31 feat: not working tlv stero
    [main.c]
2026-03-31 feat: current tx test setup
2026-03-31 feat: i2s DMA
2026-03-31 feat: adc spam
2026-03-31 feat: rough adc plot
2026-04-01 I2S slave+DMA
2026-04-01 TLV correct biasing + 24 bit
    [i2s_hw.c, main.c, tlv320adc6120_hw.c]
2026-04-01 DAC DMA
2026-04-01 grc audio flowgraph
2026-04-02 hardware fix: MCO MCK + MS5351 VDD
    [hfsdr.kicad_pcb, hfsdr.kicad_sch, rf.kicad_sch]
2026-04-02 disallow other sample rates
2026-04-02 add frequency setting button
2026-04-03 feat: pcb edits
    [hfsdr.kicad_pcb, hfsdr.kicad_sch]
2026-04-04 Fix 3d shapes
    [hfsdr.kicad_pcb]
2026-04-04 hardware: rotary encoder to TIM10
    [hfsdr.kicad_pcb, hfsdr.kicad_sch]
2026-04-04 hardware: LEDK to TIM3
    [hfsdr.kicad_pcb, hfsdr.kicad_sch]
2026-04-04 feat: gnuradio windows usb device name config
2026-04-04 hardware feat: interrupt for screen
    [hfsdr.kicad_pcb, hfsdr.kicad_sch]
2026-04-05 Drain I2S buffer before DMA start
2026-04-05 feat: added tf slot, but need to reroute some screen pins
    [hfsdr.kicad_pcb, hfsdr.kicad_sch]
2026-04-05 feat: tf card slot and screen rerouting
    [hfsdr.kicad_pcb, hfsdr.kicad_sch]
2026-04-05 feat: added silkscreen labels
    [hfsdr.kicad_pcb]
2026-04-05 Ready for production
    [audio.kicad_sch, hfsdr.kicad_pcb, hfsdr.kicad_sch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]
2026-04-07 Protection diode
    [rf.kicad_sch]
2026-04-07 unsaved stuff
    [hfsdr.kicad_pcb]
2026-04-22 feat: basic LED blinky modes - Press encoder button to switch LED modes
2026-04-22 feat: nicer LED blinky modes - press encoder
2026-04-22 feat: led blinky modes with morse code pattern
2026-04-23 feat: cursor c prototype
2026-04-23 feat: encoder toggle
2026-04-25 MCO out as ADC CLK
2026-04-25 remove dac printout
2026-04-25 Encoder code
2026-04-25 FM DMA + works completely
2026-04-25 Swap to correct endianness
    [i2s_hw.c]
2026-04-25 Colour schematics
2026-04-26 Print frequency
2026-04-26 display touch driver
2026-04-27 Increase SPI speed
2026-04-27 Add touch controller driver
2026-04-28 Reorder i2c init
2026-04-28 more filtering and faster code
2026-05-02 Add ADC voltage sampling
2026-05-03 Add timer utilities
2026-05-04 SD Card status printing
2026-05-14 tlv320 calibration parameters
2026-05-14 IQ calibration
2026-05-14 IQ calibration fixes
2026-05-14 IQ calibration polishing up
2026-05-14 IQ calibration UI fix
    [iq_calibration.cpp]
2026-05-14 Increase gain calibration range
2026-05-14 Faster init calibration
2026-05-16 chore: tinyusb optimisations didn't work
    [tusb_config.h]
2026-05-28 feat: Detect v1 board and route clock accordingly
2026-05-28 feat: bitslip reset way faster now
    [i2s.c]
2026-05-28 chore: widen i2s correct window
    [i2s.c]
2026-06-02 feat: RNG driver
2026-06-08 feat: wire up ui for new lower frequency
2026-06-08 feat: fix low freq latency
    [si5351.c]
2026-06-08 fix: low freq fix
    [si5351.c]
2026-06-18 Update README with PCB Files viewer link
    Add link to Board PCB Files viewer in README
2026-07-12 V3 changes
    [audio.kicad_sch, hfsdr.kicad_pcb, hfsdr.kicad_sch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]
2026-07-13 SD pullup + ground fill harder
    [hfsdr.kicad_pcb, hfsdr.kicad_sch]
2026-07-13 3.3V vias + JLCPCB part number
    [hfsdr.kicad_pcb]
2026-07-13 Move RST to the right
    [hfsdr.kicad_pcb]
2026-07-13 Add production files
    [BOM-hfsdr.csv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]
2026-07-13 Add TLV320ADC6120 to BOM/CPL
    [BOM-hfsdr.csv, hfsdr.kicad_pcb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]
2026-07-13 Actual real production
    [hfsdr.kicad_pcb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]
2026-07-23 Normalize I2S samples at DMA producer
2026-07-23 Add EXTI button press and recording indicator
2026-07-24 Wake SPI DMA waits from interrupt
2026-07-24 Track frequencies as uint32_t
